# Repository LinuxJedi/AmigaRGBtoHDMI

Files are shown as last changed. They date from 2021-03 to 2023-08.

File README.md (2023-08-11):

# AmigaRGBtoHDMI

LinuxJedi's designs for Amiga RGBtoHDMI boards.

**ATTENTION PI Zero 2W users**: You can now use a Pi Zero 2W with the CPLD RGBtoHDMI using the December 24th 2021 release.

## Amiga RGBtoHDMI Tester

If you are a builder of these boards I have designed a tester that safely tests these boards without requiring a Denise or Amiga. This reduces any potential damage and test if you don't have a specific Amiga model. These can be found [on Tindie](https://www.tindie.com/products/linuxjedi/amiga-rgbtohdmi-tester/).

## Choosing a CPLD

I am deliberately vague in which CPLD can be used in the boards here because many variants will work. Given chip shortages in recent years, you might want to pick any chip you can obtain rather than what is normally cheapest. I'll give a breakdown of what the model numbers look like and what to look out for. As an example I'll use `XC9572XL-10VQG44C`:

* `XC9572XL` - This part of the model number is required. Defines the type of logic chip and the number of logic cells. This is what you should search for from your supplier and then use the below to pick the right chip for you.
* `10` - is the maximum speed grade in ns. 10 is the slowest (cheapest) you can buy. The max speed this board will go is 35ns, so 10ns is plenty.
* `VQ` - means it is a QFP. You could modify the board to accept the PLCC variant, but that would require you to make some changes in KiCad. The firmware is compatible with both.
* `G` - means lead-free / RoHS compliant. Without the `G` means the legs have lead.
* `44` - number of pins. You could in-theory modify the board for more pins in KiCad. This would require a firmware change too, which in-turn means modifying the firmware loader, so I don't recommend it.
* `C` - Consumer grade (cheapest), if there is an `I` here that means "Industrial grade" (more expensive) and `A` means "Automotive grade" (crazy expensive). This mostly defines the max/min temperature the chip will work at.

My recommendation if you can obtain it, is the XC9572XL-10VQG44C (or without the `G`). But the only important parts are the `XC9572XL`, the `VQ` and the `44`.

## Projects in This Tree

### Amiga500CPLD

Amiga 500 CPLD variant that does not require a jumper and has no sparkling pixel issues.

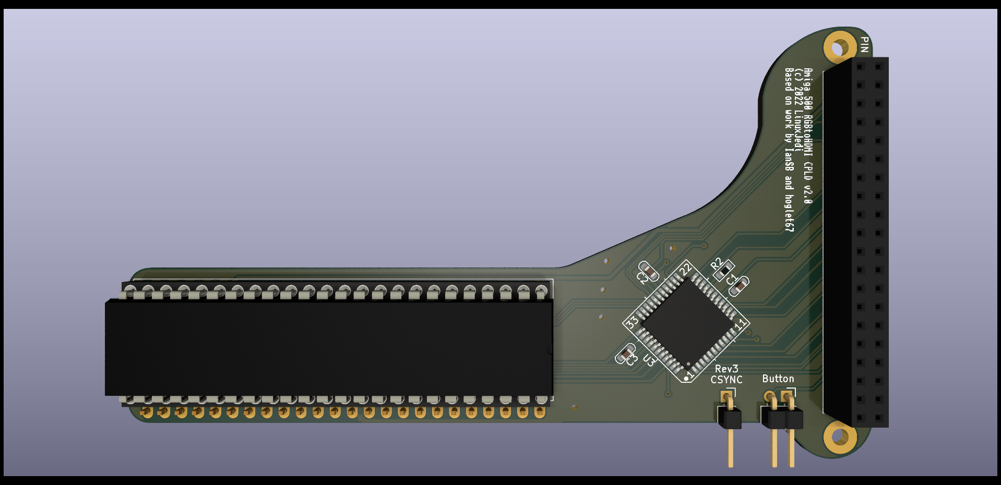
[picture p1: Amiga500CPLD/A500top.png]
Amiga 500 CPLD RGBtoHDMI


### Amiga2000CPLDSlot

Amiga 2000 CPLD variant that does not require a jumper and has no sparkling pixel issues

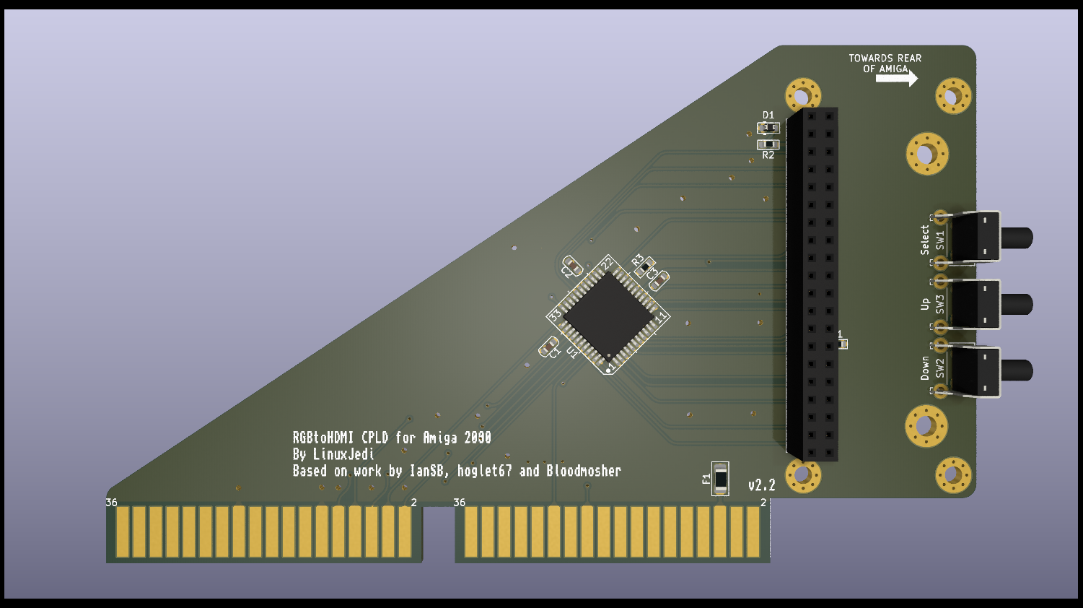
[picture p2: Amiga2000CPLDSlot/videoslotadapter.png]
Amiga 2000 CPLD Slot


### Amiga1000CPLD

Amiga 1000 CPLD variant that does not require a jumper and has no sparkling pixel issues

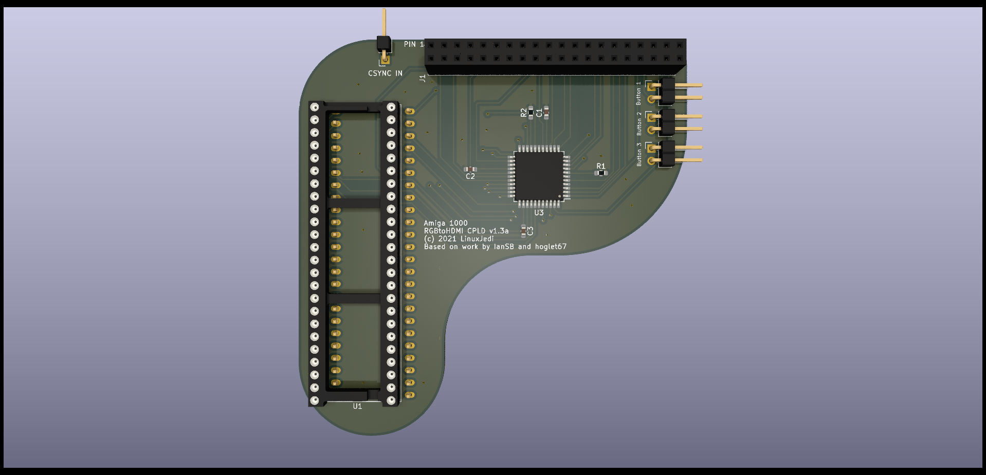
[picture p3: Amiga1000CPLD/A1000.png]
Amiga 1000 CPLD


### Legacy boards

The legacy boards directory contains:

* Amiga 2000 RGBtoHDMI v2
* Amiga 2000 CPLD RGBtoHDMI v1.2
* Amiga 2000 CPLD RGBtoHDMI v2.1

These have been superseeded by the Amiga 2000 CPLD RGBtoHDMI v2.2 board.

* Amiga 500 CPLD v1

This has been superseeded by the Amiga 500 CPLD RGBtoHDMI v2.0 board.

## Other versions

- c0pperdragon's - The excellent original c0pperdragon design can be found at: https://github.com/c0pperdragon/Amiga-Digital-Video/
- solarmon's - Improved versions of c0pperdragon's design to relocate the Pi and add additional features:https://github.com/solarmon/RGBtoHDMI

Please add pull requests to link to your variants here.

## Software

The software used for this project can be found at https://github.com/hoglet67/RGBtoHDMI/

## Troubleshooting

### Cannot use the CPLD flash menu

By default the RGBtoHDMI software is in three button mode. You need to copy the profiles in the instructions for your board which sets up a few things including the single button mode.

## Ready Built Boards

If you want a ready built board for either design please contact andrew@linuxjedi.co.uk and I can put you in touch with whoever is building / selling at a reasonable price.

Likewise if you are a someone selling these designs, please let me know if you want me to put you in touch with buyers who contact me.

I also sell some of these designs [on Tindie](https://www.tindie.com/stores/linuxjedi/).

Alternatively I've made the PCBs available on PCBWay here: https://www.pcbway.com/project/member/?bmbno=0369642B-E3DA-48

## Sponsorship

If you like these projects and have built / sold a few yourself, please consider sponsoring. R&D for these projects isn't cheap and the sponsorship money goes into more designs for the future. Links for this are can be found in the "Sponsor" button at the top of the GitHub page for this project.

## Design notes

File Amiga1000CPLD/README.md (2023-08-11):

# Amiga 1000 CPLD Adapter V1

Amiga 1000 CPLD

This adaptor uses a CPLD to pass the RGB and sync signals from the Amiga 1000 Denise socket to the Rasperry Pi Zero. It derives the pixel clock in a very different way to other designs and therefore does not require a jumper for Denise / Super Denise and has no "sparkling" pixel issues. It also has the advantage of being firmware upgradable if there are any issues found in the logic.

**NOTE:** There is an error in v1.1 boards, the text starting "IF YOU CAN READ THIS" is on the wrong side and shoud not be covered up by the Pi. The Pi goes outwards from the board.

**ATTENTION PI Zero 2W users**: You can now use a Pi Zero 2W with the CPLD RGBtoHDMI using the December 24th 2021 release.

## BOM

| Symbol | Component |
| --- | --- |
| C1, C2, C3 | 0.1uF 0603 |
| J1 | 2x20pin socket 2.54mm |
| J2 | 1pin right angle header 2.54mm |
| JButton1 - 3 | 2pin right angle header 2.54mm |
| R1 | 1K 0603 |
| R2 | 4.7K 0603 |
| U1 | 48pin DIP socket 2.54mm |
| U2 | 2x24pin SILs machined pins 2.54mm |
| U3 | XC9572XL 44pin QFP |

### Notes

- It is important that R1 is 1K due to the low value of the internal pull resistor in GPIO0 of the Pi, the other pull resistors are more flexible. If the value is too high then the software won't detect this is an Amiga board and won't show the correct firmware in the recovery menu.
- This board can be used in single button mode with just JButton1 or with three button mode.
- J2 is optional if you have already wired CSYNC to the Denise socket

## CSYNC

**NOTE**: If you have a Rejouvenator in your Amiga 1000, this patches the CSYNC and you don't need a patch wire, using the CSYNC pin can cause sync issues with a Rejouvenator.

The Amiga 1000 does not have CSYNC wired to Denise. There are two ways around this, the first is to wire CSYNC to the Denise socket on the motherboard using a patch wire. This is pin 8 of UA6 to pin 32 of Denise as below:

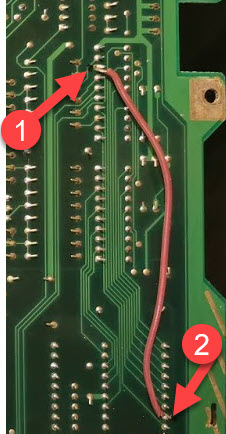
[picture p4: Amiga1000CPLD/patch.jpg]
PAL CSYNC patch


Alternatively you can use the "CSYNC IN" on the RGB to HDMI board to hook onto the relevant CSYNC signal. This is pin 8 or UA6 as can be seen below (for both PAL and NTSC):

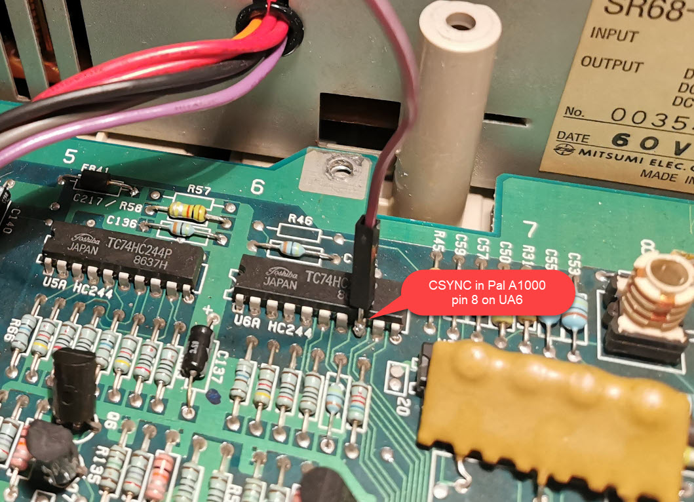
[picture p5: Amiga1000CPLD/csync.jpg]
PAL CSYNC pin


Thanks to @SirCathal for the above two photos.

## Pi Software Installation

The software on the Pi should be at least the latest 20210529 release from the [main tree](https://github.com/hoglet67/RGBtoHDMI/releases) or the latest [IanSB beta release](https://github.com/IanSB/RGBtoHDMI/releases) extracted onto a micro SD card in FAT32 format.

You need to copy some canned profile files into place for the board:

* `Amiga_CPLD_Readme/Amiga_CPLD_Setup/profile_6-12_BIT_RGB.txt` to the root of the SD card
* `Amiga_CPLD_Readme/Amiga_CPLD_Setup/Profiles/Default.txt` to the `Profiles` directory

This resolves some issues with mode switching, particularly on NTSC machines. The profile copied will automatically set `single_button_mode`.

## Flashing the CPLD

The CPLD will need flashing with the `6-12_BIT_RGB_CPLD` firmware. The other firmware options are not compatible with the profiles.

If you have followed the software steps above you will get a recovery menu, select `6-12_BIT_RGB_CPLD`, confirm and the Pi will flash the CPLD and reboot.

## Initial Setup

You may see a shimmer or wavy effect. This is because the phase is set incorrectly and needs calibration, this is a one-off easy thing to do. If you have a static image such as the Kickstart 1.3 boot screen or Workbench with no mouse movement you can use the "Auto Calibrate Video Settings" option (it will require you to select twice to activate). Alternatively you can go into the "Sampling" menu and change the "Sampling Phase" until the image looks correct. Typically 0, 3 or 5 will work fine, but it could be different in each machine.

Once calibrated choose "Save Configuration" and this will be remembered for subsequent boots.

## Buying PCBs

I've made the [PCBs available on PCBWay here](https://www.pcbway.com/project/shareproject/Amiga_1000_CPLD_RGBtoHDMI_v1_1.html).

Assembled boards are also available from me [on Tindie](https://www.tindie.com/products/linuxjedi/amiga-1000-cpld-rgbtohdmi/).

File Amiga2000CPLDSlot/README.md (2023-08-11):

# Amiga CPLD Video Slot Adapter

Amiga CPLD 2000 Slot

This adaptor uses a CPLD to pass the RGB and sync signals from the Amiga 2000 video slot to the Rasperry Pi Zero. It derives the pixel clock in a very different way to other designs and therefore does not require a jumper for Denise / Super Denise and has no "sparkling" pixel issues. It also has the advantage of being firmware upgradable if there are any issues found in the logic.

Version 2 of this board is logically identical to version 1, but is designed to be easier to build and easier for the user to install. The Pi faces the rear of the Amiga so that the HDMI can be plugged directly into it and instead of wires it uses physical buttons.

Version 2.2 has been changed to make the board smaller. It includes a fuse due to a few users misaligning the Pi, causing a sort between +5v and GND which in-turn caused the +5v line to burn. It also includes an optional LED to indicate there is power to the +5v line (that the fuse hasn't blown).

**ATTENTION PI Zero 2W users**: You can now use a Pi Zero 2W with the CPLD RGBtoHDMI using 24th December 2021 release onwards.

## BOM

| Symbol | Component |
| --- | --- |
| C1 - C3 | 0.1uF 0603 |
| J1 | 2x20pin socket 2.54mm |
| SW1 - SW3 | SKHHLQA010 90° SPST 8.35mm push button |
| R1 | 1K 0603 |
| R3 | 4.7K 0603 |
| U1 | XC9572XL 44pin QFP |
| F1 | Littlefuse 1206L075THYR |
| D1 | Any 0603 LED |
| R2 | A 0603 resistor between the LED and +5v line |

### Notes

- R1 needs to be a 1K pull resistor due to the low value internal I2C pull resisors in the Pi. If the value is too high then the software won't detect this is an Amiga board and won't show the correct firmware in the recovery menu.
- The F1 fuse can be any 1206 fuse with a hold current of 0.75A or greater. You could also just use a 0ohm resistor if you do not wish to use a fuse.
- D1 and R2 are optional, used as indication that the 5V line is being provided to the Pi and there is no fuse trip.
- This board can be used in single button mode with just SW1.
- You can use smaller push buttons but they won't reach outside of the A2000's case, this may be fine with the correct bracket.
- Brackets for the original A2000 RGBtoHDMI boards are **NOT** compatible, the mounting holes have been moved.
- It is recommended you use 4x11mm M2.5 standoffs to hold the Pi in place, alternatively you can use 10mm M2.5 standoffs and 1mm M2.5 washers.
- The board was designed in a KiCad 6.99 nightly build, you will need to use 6.99 (or higher if you are reading this after 7.0 is released) to be able to use the files.

## Pi Software Installation

The software on the Pi should be at least the latest 20211224 release from the [main tree](https://github.com/hoglet67/RGBtoHDMI/releases) or the latest [IanSB beta release](https://github.com/IanSB/RGBtoHDMI/releases) extracted onto a micro SD card in FAT32 format.

You need to copy some canned profile files into place for the board:

* `Amiga_CPLD_Readme/Amiga_2000_CPLD_Setup/profile_6-12_BIT_RGB.txt` to the root of the SD card
* `Amiga_CPLD_Readme/Amiga_2000_CPLD_Setup/Profiles/Default.txt` to the `Profiles` directory

This resolves some issues with mode switching, particularly on NTSC machines.

If you wish to use three button mode, you then need to edit `Profiles/Default.txt` and set the option `single_button_mode=0` (it is near the bottom of the file).

## Flashing the CPLD

The CPLD will need flashing with the `6-12_BIT_RGB_CPLD` firmware. The other firmware options are not compatible with this board.

If you have followed the software steps above you will get a recovery menu, select `6-12_BIT_RGB_CPLD`, confirm and the Pi will flash the CPLD and reboot.

## Initial Setup

You may see a shimmer or wavy effect. This is because the phase is set incorrectly and needs calibration, this is a one-off easy thing to do. If you have a static image such as the Kickstart 1.3 boot screen or Workbench with no mouse movement you can use the "Auto Calibrate Video Settings" option (it will require you to select twice to activate). Alternatively you can go into the "Sampling" menu and change the "Sampling Phase" until the image looks correct. Typically 0, 3 or 5 will work fine, but it could be different in each machine.

Once calibrated choose "Save Configuration" and this will be remembered for subsequent boots.

## Buying PCBs

You can buy PCBs from my store, [Retro Supplies](https://www.retrosupplies.co.uk/amiga-rgbtohdmi/rgbtohdmi-for-amiga-2000-v22-pcb-only).

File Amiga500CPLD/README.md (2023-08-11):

# Amiga 500 CPLD RGBtoHDMI

Amiga 500 CPLD RGBtoHDMI

This adaptor uses a CPLD to pass the RGB and sync signals from the Amiga 500 Denise socket to the Rasperry Pi Zero. It derives the pixel clock in a very different way to the c0pperdragon design and therefore does not require a jumper for Denise / Super Denise and has no "sparkling" pixel issues. It also has the advantage of being firmware upgradable if there are any issues found in the logic.

**ATTENTION PI Zero 2W users**: You can now use a Pi Zero 2W with the CPLD RGBtoHDMI using the December 24th 2021 release.

## BOM

| Symbol | Component |
| --- | --- |
| C1 - C3 | 0.1uF 0603 |
| J1 | 2x20pin socket 2.54mm |
| JP1 | 2pin right angle header 2.54mm |
| J2 | 1pin right angle header 2.54mm |
| R1 | 1K 0603 |
| R2 | 4.7K 0603 |
| U1 | 48pin DIP socket 2.54mm |
| U2 | 2x24pin SILs machined pins 2.54mm |
| U3 | XC9572XL 44pin QFP |

### Notes

- It is important that R1 is 1K due to the low value of the internal pull resistor in GPIO0 of the Pi, the other pull resistors are more flexible (R1 is optional as the Pi will pull this internally). If the value is too high then the software won't detect this is an Amiga board and won't show the correct firmware in the recovery menu.
- You'll need some kind of push button to connect to JP1
- J2 is optional, it is only needed for revision 3 motherboards to clip onto pin 9 of U41 on the Amiga (photo coming soon)
- The Pi mounting holes are M2.5, 11mm posts or 10mm with 1mm washers are recommended

## Pi Software Installation

The software on the Pi should be at least the latest 20210529 release from the [main tree](https://github.com/hoglet67/RGBtoHDMI/releases) or the latest [IanSB beta release](https://github.com/IanSB/RGBtoHDMI/releases) extracted onto a micro SD card in FAT32 format.

You need to copy some canned profile files into place for the board:

* `Amiga_CPLD_Readme/Amiga_CPLD_Setup/profile_6-12_BIT_RGB.txt` to the root of the SD card
* `Amiga_CPLD_Readme/Amiga_CPLD_Setup/Profiles/Default.txt` to the `Profiles` directory

This resolves some issues with mode switching, particularly on NTSC machines. The profile copied will automatically set `single_button_mode`.

## Flashing the CPLD

The CPLD will need flashing with the `6-12_BIT_RGB_CPLD` firmware. The other firmware options are not compatible with the profiles.

If you have followed the software steps above you will get a recovery menu, select `6-12_BIT_RGB_CPLD`, confirm and the Pi will flash the CPLD and reboot. You can then jump to the Initial Setup section below.

## Initial Setup

You may also a shimmer or wavy effect. This is because the phase is set incorrectly and needs calibration, this is a one-off easy thing to do. If you have a static image such as the Kickstart 1.3 boot screen or Workbench with no mouse movement you can use the "Auto Calibrate Video Settings" option (it will require you to select twice to activate). Alternatively you can go into the "Sampling" menu and change the "Sampling Phase" until the image looks correct. Typically 0, 3 or 5 will work fine, but it could be different in each machine.

Once calibrated choose "Save Configuration" and this will be remembered for subsequent boots.

## Buying PCBs

I've made the [PCBs available on PCBWay](https://www.pcbway.com/project/shareproject/Amiga_500_CPLD_RGBtoHDMI_v2_fb52eff9.html).

You can also purchase PCBs from me [via Tindie](https://www.tindie.com/products/linuxjedi/amiga-500-rgb-to-hdmi-pcb/).

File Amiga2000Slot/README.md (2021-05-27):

# Amiga Video Slot Adapter V2

**NOTE:** This is now a legacy project, please see the Amiga 2000 CPLD version also in this GitHub repository.

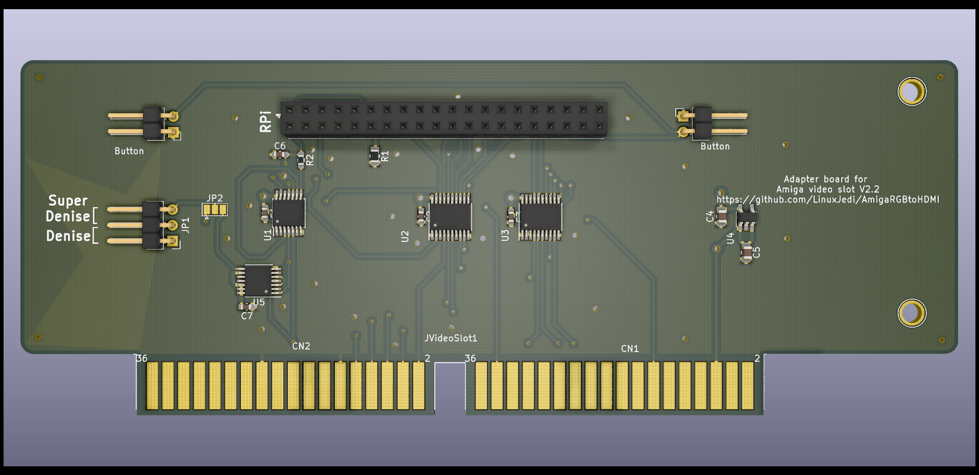
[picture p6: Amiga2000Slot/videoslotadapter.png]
Amiga 2000 Slot


This adapter builds on the ideas from the Amiga Denise adapter V2, adapted for use in big box Amiga video slots. LinuxJedi's Version 2 is based on Bloodmosher's V1 design but has been modified for reliability and to provide timing options.

The main differences from the Amiga Denise V2 are:
- The 7MHZ signal is derived via C1 XNOR C3 since 7MHZ is not available directly from the video slot
- Two button connectors allow for both a rear slot cover bracket button and another to be used, mounted wherever desired

The main differences from the V1 slot adaptor are:
- ICs moved to more appropriate locations
- Fixed floating inputs on U5
- Added ground pour and more grounding points for RGB and Pi
- Manually rerouted everything (fewer signal vias)
- Added option to use U1 for the inverted C1, C3 XNOR (which makes it an XOR)
- Added RC based delay option
- Input capacitor added to the regulator
- Rounded the corners a little more

## LinuxJedi's build notes

### Options

 - For U1 to handle Super Denise timing add 0ohm between pin 1 and 2 of JP2
 - For U5 to handle Super Denies timing add 0ohm between pin 2 and 3 of JP2
 - C6 is an optional capacitor for timing delay, 47pF has been recommended by some but can be left unpopulated
 - R2 is a resistor for timing delay, it needs to be populated, only 0ohm has been tested

### Recommended build

This is what has worked for me, YMMV.

 - Leave U5 and C7 unpopulated
 - 0ohm 0603 (or wire/solder short) between pins 1 and 2 of JP2
 - 0ohm 0603 in R2
 - C6 unpopulated or 47pF 0603
 - Use TI 74LVC ICs (Toshiba 74VHC for U1 has also been tested with this design and appear to work)
 - Use a regulator that is rated for 300mA or higher (I use NCP161 regulators in my builds)

### Recommended ordering

If you are ordering from JLCPCB I recommend the following:

 - Surface Finish: ENIG
 - Gold Fingers: Yes
 - 45° finger chamfered: yes

## Installation notes

- Set the Denise jumper according to which Denise is in your Amiga (Super Denise for 8373, Denise for 8362)
- Orient the PCB such that the end with bracket mounting holes faces the rear of the machine

## Sparkles in the image

There are a few things to try. First if the sparkling is extreme, try swapping the Denise/Super Denise jumper to the opposite setting, this changes the clock used for the RGB timing. Then you can try a 47pF capacitor in C6 and using 74VHC ICs instead of 74LVC.

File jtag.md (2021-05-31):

# JTAG pins

The JTAG is accessible on the Pi GPIO header, so you can plug pins into the header to use a JTAG programmer to flash it. If you don't have a JTAG programmer I have [documented how to build one out of a Raspberry Pi](https://linuxjedi.co.uk/2020/12/01/programming-xilinx-jtag-from-a-raspberry-pi/). Note that the GPIO pins xc3sprog use for JTAG are different to the RGBtoHDMI GPIO JTAG pins.

The JTAG pins are:

| GPIO number | GPIO pin | Signal |
| --- | --- | --- |
| N/A | 1 or 17 | 3v3 |
| N/A | 6, 9, 14, 20, 25, 30, 34 or 39 | GND |
| 0 | 27 | TDI |
| 1 | 28 | TMS |
| 20 | 38 | TCK |
| 24 | 18 | TDO |

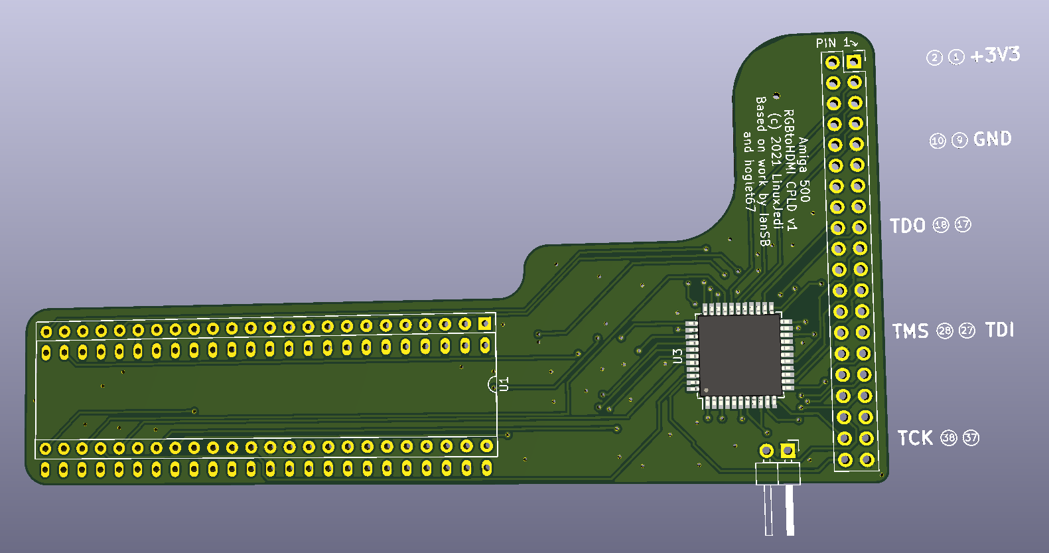
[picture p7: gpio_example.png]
GPIO Example


If you are using Pi xc3sprog method from the link above you will need to compile the JED file which can be done in the free Xilinx ISE Design Suite.

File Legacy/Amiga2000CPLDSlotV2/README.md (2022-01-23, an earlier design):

# Amiga CPLD Video Slot Adapter

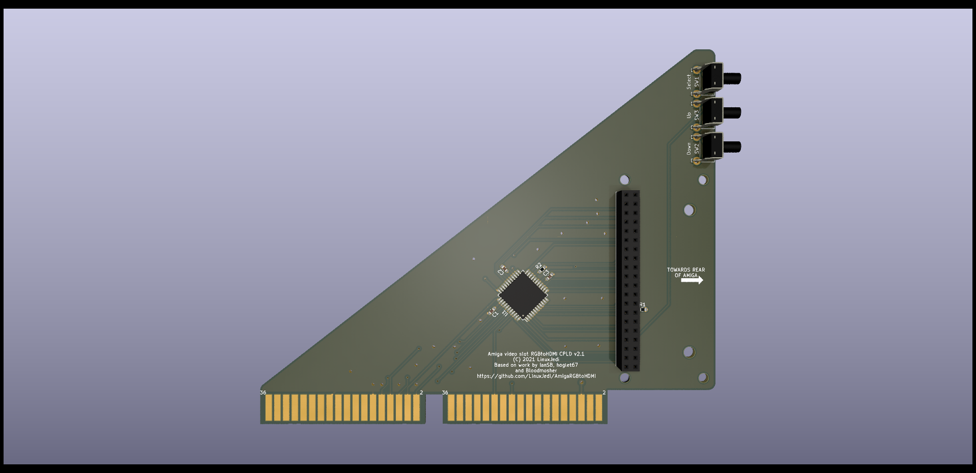
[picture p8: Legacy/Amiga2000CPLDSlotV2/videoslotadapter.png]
Amiga CPLD 2000 Slot


This adaptor uses a CPLD to pass the RGB and sync signals from the Amiga 2000 video slot to the Rasperry Pi Zero. It derives the pixel clock in a very different way to other designs and therefore does not require a jumper for Denise / Super Denise and has no "sparkling" pixel issues. It also has the advantage of being firmware upgradable if there are any issues found in the logic.

Version 2 of this board is logically identical to version 1, but is designed to be easier to build and easier for the user to install. The Pi faces the rear of the Amiga so that the HDMI can be plugged directly into it and instead of wires it uses physical buttons.

**ATTENTION PI Zero 2W users**: You can now use a Pi Zero 2W with the CPLD RGBtoHDMI using 24th December 2021 release onwards.

## BOM

| Symbol | Component |
| --- | --- |
| C1 - C3 | 0.1uF 0603 |
| J1 | 2x20pin socket 2.54mm |
| SW1 - SW3 | SKHHLQA010 90° SPST 8.35mm push button  |
| R1 | 1K 0603 |
| R2 | 4.7K 0603 |
| U1 | XC9572XL-10VQG44C |

### Notes

- R1 needs to be a 1K pull resistor due to the low value internal I2C pull resisors in the Pi. If the value is too high then the software won't detect this is an Amiga board and won't show the correct firmware in the recovery menu.
- This board can be used in single button mode with just SW1.
- You can use smaller push buttons but they won't reach outside of the A2000's case, this may be fine with the correct bracket.
- Brackets for the original A2000 RGBtoHDMI boards are **NOT** compatible, the mounting holes have been moved.
- It is recommended you use 4x11mm M2.5 standoffs to hold the Pi in place, alternatively you can use 10mm M2.5 standoffs and 1mm M2.5 washers.

## Pi Software Installation

The software on the Pi should be at least the latest 20211224 release from the [main tree](https://github.com/hoglet67/RGBtoHDMI/releases) or the latest [IanSB beta release](https://github.com/IanSB/RGBtoHDMI/releases) extracted onto a micro SD card in FAT32 format.

You need to copy some canned profile files into place for the board:

* `Amiga_CPLD_Readme/Amiga_2000_CPLD_Setup/profile_6-12_BIT_RGB.txt` to the root of the SD card
* `Amiga_CPLD_Readme/Amiga_2000_CPLD_Setup/Profiles/Default.txt` to the `Profiles` directory

This resolves some issues with mode switching, particularly on NTSC machines.

If you wish to use three button mode, you then need to edit `Profiles/Default.txt` and set the option `single_button_mode=0` (it is near the bottom of the file).

## Flashing the CPLD

The CPLD will need flashing with the `6-12_BIT_RGB_CPLD` firmware. The other firmware options are not compatible with this board.

If you have followed the software steps above you will get a recovery menu, select `6-12_BIT_RGB_CPLD`, confirm and the Pi will flash the CPLD and reboot.

## Initial Setup

You may see a shimmer or wavy effect. This is because the phase is set incorrectly and needs calibration, this is a one-off easy thing to do. If you have a static image such as the Kickstart 1.3 boot screen or Workbench with no mouse movement you can use the "Auto Calibrate Video Settings" option (it will require you to select twice to activate). Alternatively you can go into the "Sampling" menu and change the "Sampling Phase" until the image looks correct. Typically 0, 3 or 5 will work fine, but it could be different in each machine.

Once calibrated choose "Save Configuration" and this will be remembered for subsequent boots.

## Buying PCBs

I've made the [PCBs available on PCBWay](https://www.pcbway.com/project/shareproject/Amiga_2000_CPLD_RGBtoHDMI_v2_1_83f23b25.html).

A limited edition version of this board with the LinuxJedi logo containing a glowing lightsaber can be found [on Tindie](https://www.tindie.com/products/linuxjedi/amiga-2000-rgb-to-hdmi/).

## Bracket

Comming soon.

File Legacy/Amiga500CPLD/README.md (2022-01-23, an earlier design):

# Amiga 500 CPLD RGBtoHDMI

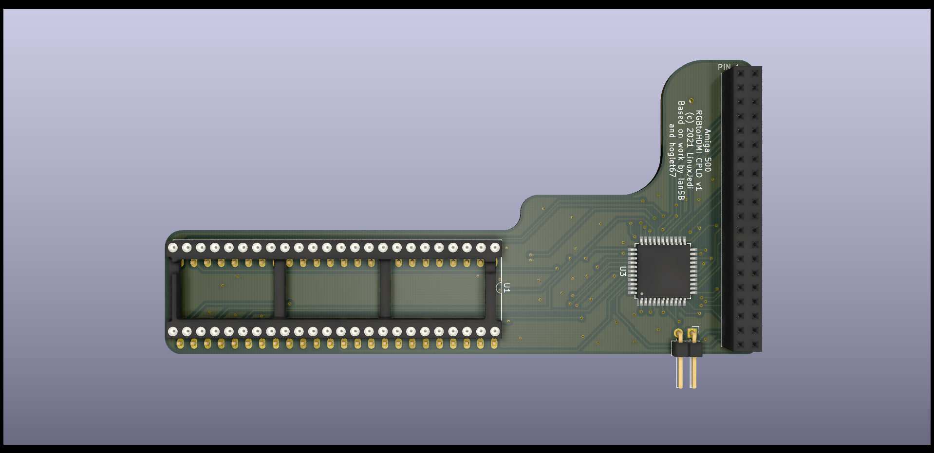
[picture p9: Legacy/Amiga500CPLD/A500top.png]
Amiga 500 CPLD RGBtoHDMI


This adaptor uses a CPLD to pass the RGB and sync signals from the Amiga 500 Denise socket to the Rasperry Pi Zero. It derives the pixel clock in a very different way to the c0pperdragon design and therefore does not require a jumper for Denise / Super Denise and has no "sparkling" pixel issues. It also has the advantage of being firmware upgradable if there are any issues found in the logic.

**ATTENTION PI Zero 2W users**: You can now use a Pi Zero 2W with the CPLD RGBtoHDMI using the December 24th 2021 release.

## BOM

| Symbol | Component |
| --- | --- |
| C1 | Optional 10uF 1206 |
| C2, C3, C4 | 0.1uF 0603 |
| J1 | 2x20pin socket 2.54mm |
| JP1 | 2pin right angle header 2.54mm |
| R1, R2 | 1K 0603 |
| R3 | 4.7K 0603 |
| U1 | 48pin DIP socket 2.54mm |
| U2 | 2x24pin SILs machined pins 2.54mm |
| U3 | XC9572XL-10VQG44C |

### Notes

- It is important that R2 is 1K due to the low value of the internal pull resistor in GPIO0 of the Pi, the other pull resistors are more flexible (R1 is optional as the Pi will pull this internally). If the value is too high then the software won't detect this is an Amiga board and won't show the correct firmware in the recovery menu.
- In my own builds I do not populate C1. You could use this for a 3.9v LED I guess
- You'll need some kind of push button to connect to JP1

## Pi Software Installation

The software on the Pi should be at least the latest 20210529 release from the [main tree](https://github.com/hoglet67/RGBtoHDMI/releases) or the latest [IanSB beta release](https://github.com/IanSB/RGBtoHDMI/releases) extracted onto a micro SD card in FAT32 format.

You need to copy some canned profile files into place for the board:

* `Amiga_CPLD_Readme/Amiga_CPLD_Setup/profile_6-12_BIT_RGB.txt` to the root of the SD card
* `Amiga_CPLD_Readme/Amiga_CPLD_Setup/Profiles/Default.txt` to the `Profiles` directory

This resolves some issues with mode switching, particularly on NTSC machines. The profile copied will automatically set `single_button_mode`.

## Flashing the CPLD

The CPLD will need flashing with the `6-12_BIT_RGB_CPLD` firmware. The other firmware options are not compatible with the profiles.

If you have followed the software steps above you will get a recovery menu, select `6-12_BIT_RGB_CPLD`, confirm and the Pi will flash the CPLD and reboot. You can then jump to the Initial Setup section below.

## Initial Setup

You may also a shimmer or wavy effect. This is because the phase is set incorrectly and needs calibration, this is a one-off easy thing to do. If you have a static image such as the Kickstart 1.3 boot screen or Workbench with no mouse movement you can use the "Auto Calibrate Video Settings" option (it will require you to select twice to activate). Alternatively you can go into the "Sampling" menu and change the "Sampling Phase" until the image looks correct. Typically 0, 3 or 5 will work fine, but it could be different in each machine.

Once calibrated choose "Save Configuration" and this will be remembered for subsequent boots.

## Buying PCBs

I've made the [PCBs available on PCBWay](https://www.pcbway.com/project/shareproject/Amiga_500_CPLD_RGBtoHDMI_v1.html)

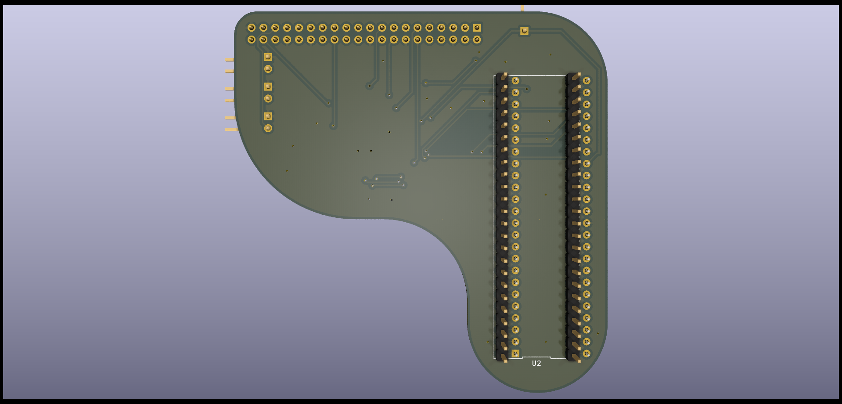
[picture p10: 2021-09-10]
Amiga1000CPLD/A1000 bottom.png

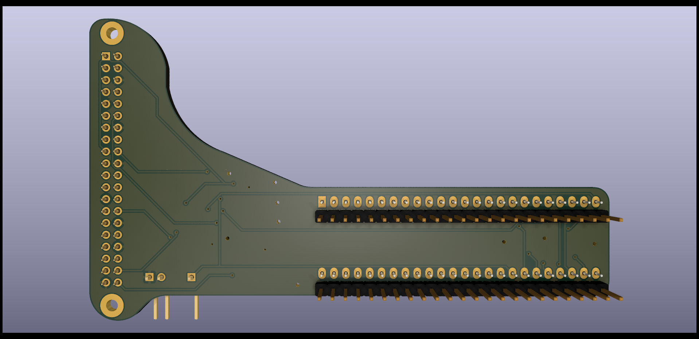
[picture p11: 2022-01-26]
Amiga500CPLD/A500bottom.png

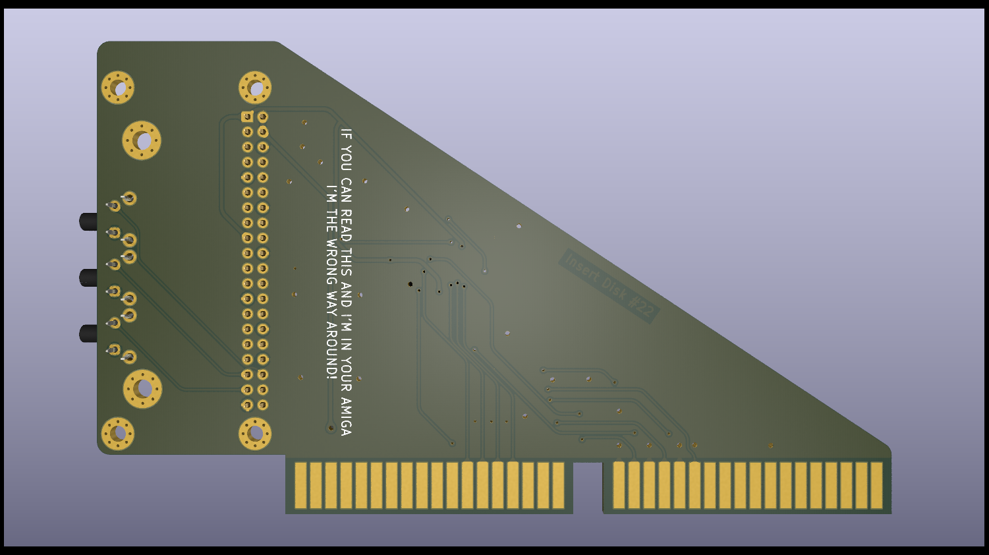
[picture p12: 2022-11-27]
Amiga2000CPLDSlot/videoslotadapter_bottom.png

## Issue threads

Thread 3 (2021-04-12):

Add option for two more buttons to the A2000 CPLD version

LinuxJedi, 2021-04-12:
This was requested by someone, can't think of a reason not to.

LinuxJedi, 2021-04-12:
Fixed in v1.1

Closed 2021-04-12.

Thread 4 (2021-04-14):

Add FF OSD header

LinuxJedi, 2021-04-14:
Requested via Discord to add it to the CPLD designs

LinuxJedi, 2021-04-17:
This is currently blocked as the GPIO pin for FF OSD is currently used for JTAG in the CPLD design.

LinuxJedi, 2021-05-10:
Blocked issue is fixed, but the OSD will have sync issues with the current design of the interface. Leaving this open for now but not a high priority until a better way is found.

LinuxJedi, 2021-12-08:
Closing this for now as others have incorporated it into their designs.

Closed 2021-12-08.

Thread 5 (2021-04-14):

Please adjust the new CPLD Adapter for the A1000

SirCathal, 2021-04-14:
Hello, I'm really looking forward to the CPLD version for the A500. I've already ordered components.
But would it be possible that you adapt the A500 version so that it fits into the A1000.
In the A1000, the Denise chip is rotated 180 ° compared to the A500. That means with the new adapter the Pi would hang out of the front of the case. So it doesn't fit in.

It would look like this:
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

Based on your new adapter, the Pi would simply have to be on the other side, not to the right but to the left (see photo for explanation).
So it could work so that neither the front nor the power supply are in the way.
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

Since the A1000 always has flickering pixels, because the timing is just a little different there than in the newer Amigas, your solution would be perfect for the A1000.

@LinuxJedi
It would be totally great if you could adjust that accordingly. Unfortunately, I can't design circuit boards, but if you can do that I would test it right away.

LinuxJedi, 2021-04-14:
Sure, I won't be able to until this weekend at the earliest, but should only take an hour or so.

SirCathal, 2021-04-14:
That would be great! Time is not a problem. Here in Germany I have to wait a week or two for the chips that I ordered in the US to arrive anyway.
Here they were unfortunately not in stock or significantly more expensive.
Thank you very much in advance!

LinuxJedi, 2021-04-17:
@SirCathal I've just merged #6 which might do the trick. Let me know what you think.

rlake, 2021-05-03:
Waiting on boards to arrive but can give this a go on an NTSC board assuming a faster (5 or 7) CPLD is fine.

LinuxJedi, 2021-05-03:
> Waiting on boards to arrive but can give this a go on an NTSC board assuming a faster (5 or 7) CPLD is fine.

Yes, a faster CPLD will work but is more expensive, Mouser still have stock if that helps: https://www.mouser.co.uk/ProductDetail/Xilinx/XC9572XL-10VQ44C

I should note that you will need to modify your A1000 board to add CSYNC to the Denise socket. I'll soon do an updated revision soon to optionally hook a wire elsewhere to provide that. @SirCathal has details of the change that is required.

rlake, 2021-05-03:
Sounds good, I somehow missed the non-RoHS version but no matter.

I'll try a clip onto pin 2 of U7A/MC1377 for CSYNC.

SirCathal, 2021-05-04:
In My PAL A1000, I soldered a cable from pin 8 on UA6 to pin 32 of the Denise socket under the Moterboard to get CSYNC.
Here is the fix from below the mainboard.
(1) is Pin 8 of UA6
(2) is Pin 32 of the Denise socket.
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

@LinuxJedi all parts for your A1000 adapter arrived. A friend soldered it for me because I'm not so good in soldering SMD stuff.
He already tested it with his A500 board (he don't have a A1000). There it worked very good. Now he sanded it to me and it will arrive this week. Then I will do the final Test in my A1000.
If it's done I will post Pictures and a Video.

LinuxJedi, 2021-05-04:
Perfect, thank you. When I have confirmation it is good I'll update the files to add a place to hook a wire into my board instead and write up some documentation. Can you please take a photo of the top of UA6 for me? It will help me mark in the documentation what to do.

SirCathal, 2021-05-04:
No Problem, here is the Foto. Please make sure that this is for the PAL Board with no PiggyBoard.
As far as I Know, the NTSC Board has the signal somewhere else.
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

SirCathal, 2021-05-04:
I Hope I can do test final test at the weekend. That the parcel did not move today, I think DHL hates me....

SirCathal, 2021-05-08:
@LinuxJedi
I can confirm, The A1000 Adapter works and fits perfectly in my Pal A1000 with CSYNC added as in my description above.
Thank you for this wonderful peace of hardware.

LinuxJedi, 2021-05-08:
> @LinuxJedi
> I can confirm, The A1000 Adapter works and fits perfectly in my Pal A1000 with CSYNC added as in my description above.
> Thank you for this wonderful peace of hardware.

Excellent! Glad to hear it! Can I be cheeky and ask for a photo of the motherboard with it in please? I want to see how close my estimates based on photos were :)

SirCathal, 2021-05-08:
No Problem, here the Pictures.
Ignore the black wire, it's only a ground wire to the Pi0 from old experiments.

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

rlake, 2021-05-08:
Just trying this out now. I used a JTAG cable to program the chip through GPIO, extracted RGBtoHDMI_20210322_f771e51 and changed single_button_mode=1 in Default.txt

Booting gives the CPLD Recovery Menu, which sounds wrong unless I missed some instructions. Any suggestion for where to check next? I also need to learn how to use the menu system

rlake, 2021-05-09:
Found my serial cable and well, it doesn't look good for my build for some reason! I'll have to investigate more into how the detection works before I try reflowing and/or programming again:

```
Unknown CPLD: identifier = fff
EMMC: BCM2708 controller power-cycled
Keycount = 0
CPLD  Design: Unknown
CPLD Version: f.f
```

Anyway, here's the fit for an NTSC Amiga 1000. It's a little snug with that brown "DL1" component but it's not too bad with the "piggy board". For CSYNC I'm just using a test clip from pin 8 of U6A (CSY* according to my Zorro schematics) to a wire fed under the socket to Denise pin 32.

I suppose if there's something to wish for on a final rev it'd be some optional headers for 3-button mode and the uart tx+gnd just in case! 😀

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

LinuxJedi, 2021-05-09:
> Just trying this out now. I used a JTAG cable to program the chip through GPIO, extracted RGBtoHDMI_20210322_f771e51 and changed single_button_mode=1 in Default.txt
>
> Booting gives the CPLD Recovery Menu, which sounds wrong unless I missed some instructions. Any suggestion for where to check next? I also need to learn how to use the menu system

The recovery menu doesn't work in single_button_mode in that version unfortunately, there is a bug which has been fixed but not made it into the main releases yet.

I highly recommend using the latest beta from here: https://github.com/IanSB/RGBtoHDMI/releases

Then you can set single_button_mode=1 in Default.txt and use the recovery menu properly to flash the board. It also has some NTSC specific fixes in it.

rlake, 2021-05-09:
Yeah that helped a lot! This time I generated an XSVF from Xilinx tools and dropped it into the 6-12 bit and recovery folders, but the menu didn't display the file (not sure how that's determined) so I went with the BBC firmware. RPi programmed fine:

```
CPLD  Design: 6-12_BIT_RGB
CPLD Version: 9.2
```

But that leaves me with a grey screen and no means to get back into recovery menu (to my knowledge, button doesn't have any effect; serial console shows it booting). I can't explain why the Xilinx tools with my Digilent/Adept adapter/plugin "verified" the firmware at first (and didn't detect) but the RPi programmed firmware is good.

I'll try and dig through the software later to see what's going on with the menu, recovery, why it's in "Acorn" mode etc. Hardware seems good so far though, stuck with software/tools debugging. :)

LinuxJedi, 2021-05-10:
Latest commit to main adds two more optional buttons and an optional pin to hook CSYNC into and a README is added. rlake's issues are being diagnosed elsewhere. I'm going to close this for now. Please feel free to open a new issue with any issues found.

Closed 2021-05-10.

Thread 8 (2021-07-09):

New build, single button mode not working, can't flash.

dabonetn, 2021-07-09:
I just built up a board, and trying the Beta36 software, and I can't get the menus to work, it acts like it's not in single button mode, so it just returns to the main menu, and if I hold it down it turns scanlines on and off.

the default.txt has been copied from Amiga_CPLD_Readme\Amiga_CPLD_Setup\Profiles to the root of the card.
And the next to the last line is.

single_button_mode=1

Any suggestions? I've tried 4gb and 32gb cards, formatted fat32 with 4k clusters.

LinuxJedi, 2021-07-09:
Hi,

The instructions state you need to copy:
* `Amiga_CPLD_Readme/Amiga_CPLD_Setup/profile_6-12_BIT_RGB.txt` to the root of the SD card
* `Amiga_CPLD_Readme/Amiga_CPLD_Setup/Profiles/Default.txt` to the `Profiles` directory

Copying `Default.txt` to the root instead of the `Profiles` directory will not overwrite the stock `Default.txt` and therefore will not enable `single_button_mode`.

dabonetn, 2021-07-09:
That was it.. Problem lies between keyboard and chair.. Thanks..

Closed 2021-07-09.

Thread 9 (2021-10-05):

Gerber files, graphics need to be moved to silkscreen layer

goose2000, 2021-10-05:
Hi, I ran into the issue today at PCBWay :

Hi John, For PCB order No. W234910ASB2,please see the image,the cartoon image can not be made on solder mask layer because the width of line is too thin. Please consider move it to silkscreen layer,and expand line to 0.075mm at least. Waitting for your new gerber file.

They want the image moved and line bigger. I don't know how to edit the gerber files / PCB software.

https://pcbwayfile.s3-us-west-2.amazonaws.com/msgfile/21/10/04/2214162170132t.png

LinuxJedi, 2021-10-06:
Huh... they didn't have a problem with it before now. I'll remove the image and update the gerbers when I get time later today.

Closed 2021-10-06.

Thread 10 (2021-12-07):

Help: Pi Zero not powering up

maded2, 2021-12-07:
hi,
   Thank you for the putting the work in for this project.

   I have A500 Rev 3 board.  I've just made this board.  It appears that the Pi Zero wouldn't boot up when plugged into the RGBtoHDMI adaptor, but it appears to boot when not plugin.   Any pointer to debug will be very helpful.  I've checked the soldering and it appears to be good.

thanks,
eddie

maded2, 2021-12-07:
fantastic,  so will this caused the Pi zero not booting up?

LinuxJedi, 2021-12-07:
OK, found the schematic (https://museum.syssrc.com/static/Amiga_500_Introduction.pdf).

The Pi should be booting but won't do anything until it gets a CSYNC signal, the button will not function either. If you are lucky you might see a flash of colour but this usually happens faster than monitors can show. The monitor will go back into DPMS immediately.

Did you get as far as the firmware recovery screen for first time boot?

The workaround for rev 3 CSYNC is to connect U41 pin 9 to pin 32 on Denise, this will provide CSYNC on the Denise which the RGBtoHDMI board can pick up.

maded2, 2021-12-07:
ok, I will give it a try tomorrow.  I haven't make it to the recovery screen yet, as I said the Pi zero appears not to boot at all.

LinuxJedi, 2021-12-07:
OK, there may be something else at play as well then. Can you please attach a good as possible photo of the CPLD soldering and the underside surface mount soldering?

Also did the RGB standard Amiga connector work whilst the board was plugged in?

maded2, 2021-12-07:
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

the Amiga is working as expected.  I get a the B&W composite video signal and it display fine (I don't have a CRT to use the RGB video out, that's why I want to get this board to work)

LinuxJedi, 2021-12-07:
A couple of things to check, first of all there might be a solder bridge here:

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

Also, with a multimeter try to do a continuity test on one of the capacitors on the underside, this would indicate a short between 3.3v and ground which would stop the Pi booting.

maded2, 2021-12-07:
I will reflow those pins tomorrow.  continuity test  is showing a short across the capacitor.  Will reflow all the passives as well tomorrow under the scope.

many thanks.

LinuxJedi, 2021-12-07:
You might need to replace the capacitors if the reflow doesn't fix it, occasionally you can get a bad one. The short will definitely be the problem. The two pins to the right of the ones I highlighted I think are 3.3v and GND, so check if there is a short there too. Possibly check the right side of the chip, I can't tell if it is blur or if there are bridges there.

maded2, 2021-12-08:
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

fantastic, everything working now.  one of the smd passive had a short.   Then there was no sync signal.  I use your suggestion of  csync from U41 pin9 workaround, this works really well.

many thanks for your help

Closed 2021-12-08.

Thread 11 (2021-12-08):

Got one working (A1000)! But can't clear up noise.

goose2000, 2021-12-08:
Hi - Finished building and flashing and booting up v3 board tonight. It looks pretty good, but seems no matter I still get lines and a little noise even after I run the autoconfiguration. Tried a few times. My CSYNC is connected to the RGBtoHDMI pin and soldered to the U6 chip.

The TV I am using is a small and odd size resolution: 1360 x 768 - It's like a RV travel TV.

Thanks for any ideas

LinuxJedi, 2021-12-08:
Can you please take a photo of the output, a photo of the main menu on the software and a photo of the sampling menu? This should help figure out where the problem lies.

Also, are you running the auto-calibration on a static image (eg. Kickstart 1.2/1.3 screen?), it will make a bad decision if there is any motion on the image.

goose2000, 2021-12-09:
Think we can close this one L.J. - I moved on to a second board, where I did a better job on the CLPD. Hooked it up, flashed this one and it performs beautifully ! So, I had some build quality on original board.

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

LinuxJedi, 2021-12-10:
I'm glad you got it working. It could well have been a tiny solder bridge around a couple of the Xilinx pins that did it. Sometimes they are invisible to the naked eye (I've fried a Pi Zero with one thinner than a human hair).

LinuxJedi, 2021-12-10:
I believe that is the output of two different colours shorted. So that would definitely do it. A bit of flux and a light touch of the soldering iron should fix that.

goose2000, 2021-12-10:
Yep!
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
!

Closed 2021-12-09.

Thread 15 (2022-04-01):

Unable to flash (in 1 button mode)

Sedrickgates, 2022-04-01:
Hi,
I have successfully flashed 1 board and it works like a charm.... but all subsequent ones won't flash :-(
It could be due to bad CPLD of course but 1 out of 10 is a bit odd.
I have tried to clear the CPLD using the remove text file but no luck.
Interface shows Current=3-12BITBBC  xx.x (See picture). I have never flashed them, they are brand "new". Could it be that they are aready programmed with another set? (those might be pulled parts)
Is there a way to forceflash/forceclear the CPLD from the Raspberry software using the Header?
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

 Thanks
 Cédric

LinuxJedi, 2022-04-01:
The versioning is working by pulling an ID from the CPLD and matching that up with details in the Pi's software. If they were from a Chinese supplier it is more than possible they were pulled from *something* and the software is reading this as the BBC version.

Equally possible is the Pi itself could have a damaged GPIO. I would check this too. Details on how to use GPIOtest can be found here (make sure the Pi is not connected): https://forums.raspberrypi.com/viewtopic.php?t=180505

Finally, what exactly happens when you try to overwrite the flash? Does it show a flashing text or does it return immediately?

Sedrickgates, 2022-04-02:
Hi,
Thanks for your quick reply.
For GPIO, all is good and tried 2 RPi,.
I am able to erase / (re)program 1 of the CPLD and it works on the Amiga. 9 others are failures.
Here are 2 videos.
First one  is with the working one (debug/erasing/flashing).
The other is What I get with a bad CPLD (debug/erasing/flashing)
https://youtu.be/uMGF5WQTbJ0
https://youtu.be/LkSqpSJheZQ

I have opened a dispute on ALI /PayPal.
The supplier is my trusted Altera MAXII provider for PiSrorms and has been flawless.
But for those X9572XL it is not the same story :-(
Thanks again for your work and  this fast reply.
Br.
Cédric

LinuxJedi, 2022-04-02:
Things to check:
R1 - make sure it is a 1K resistor and not a higher value
R2 - make sure this is soldered correctly

Check pins 44, 11, 10, 9, 24 for solder bridges.

Assuming that is all good, then I would say that it is safe to assume the other CPLDs probably aren't good (or are at least not what is badged).

Sedrickgates, 2022-04-02:
Will do that today  ;-)
I have checked  solder bridges in production as I solder under microscope. Most board are looking that way.
 https://photos.app.goo.gl/Ty7gdCurFB7EDUAR7

Boards are JLCPCB FR4 150 type (thicker than 140)
For R value, true that I have not checked them. From What I have read I could even remove it as RPi would take care of the pull.

Thanks a million. Will try ASAP.

LinuxJedi, 2022-04-03:
Both R2 and R1 are pulls to communicate something to the Pi. R2 is pretty flexible in value but R1 has to be 1K because on the Pi this is an I2C pin, any higher and it doesn't pull. If you don't have R1 or it is too high a value then the Pi will think this is a legacy BBC board and misbehave.
The pulls that aren't required are for the buttons and are already removed on this design.

Sedrickgates, 2022-04-03:
I'll swap resistor. Value is between 600 and 1K on my cheap multimeter. I'll compare from the working one. Resistors are from same batch.
I'll report back.
Thk

LinuxJedi, 2022-04-03:
600-1K should be fine. I've seen a couple of people accidentally put a 4.7K there once or twice and it caused the firmware flashing menus to misbehave.

Off the top of my head, R2 tells the Pi there is a CPLD, without it the Pi will think it is a fixed-logic RGBtoHDMI board.

Sedrickgates, 2022-04-04:
I tried with 910ohm resistor to be sure my 1k serie would be bad. On multi 1k reads 1k and 910 ohm reads 910 as well.
Swapping did not fix issue so I can confirm CPLD is more than likely bad.
New batch of CPLD is coming soon.
Thanks for your help and all the details that I can use to troubleshoot the build.
My sincere respect to you!!!!

tyristori, 2022-06-20:
I've build over a 100 of these and I have two Zeros and one Zero 2 that have damaged GPIO that will cause this issue.

I was pulling my hair out the first time it happened before I figured out it was the GPIO.

LinuxJedi, 2022-06-20:
Ah, yes. I suspect a damaged GPIO could do this.

Sedrickgates, 2022-06-20:
In my case I use rose RPi for testing Pistorms with EMU68. GPIO are fine. I also ran GPIO test.
And a pulled CPLD from a working devboards works fine too.
Got the bad parts reimbursed
But thanks tor tour input.

LinuxJedi, 2022-11-27:
Closing this one for now.

Closed 2022-11-27.

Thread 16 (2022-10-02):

Other CPLD

shred, 2022-10-02:
The XC9572XL seems to be out of stock everywhere until 2024, at least for hobbyists.

Is there a way to redesign the adapters using a CPLD that is still available? (I don't know much about CPLDs, so I'm sorry if this is a really stupid question. :wink: )

LinuxJedi, 2022-10-02:
One builder has done a redesign to use the PLCC variant which had some availability. But I believe they are out of stock in most places now too. BGA variant is still available but it is not cheap (or easy to solder if you don't have the equipment to do it).

As for other brands of CPLD, it is possible, but the same supply issue pretty much exists and the flashing software would need to be updated accordingly (this may be more difficult).

shred, 2022-10-02:
Well, since the Raspberry Pi Zero is also out of stock (or sold at online auctions for 50€ or more), I guess we'll have to wait patiently.

Thank you for the answer. I will close this ticket.

Closed 2022-10-02.

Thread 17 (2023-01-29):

Video artifacting

mudmin, 2023-01-29:
Hi!  Thanks so much for this awesome project.

I'll be the first to say that I don't know what I don't know when it comes to Amiga stuff.  I've assembled a board and tested every pin for shorts with the mm, but I'm getting some artifacting on the screen. I'm guessing you've seen this before and might be able to point me in the right direction.  Here's a little 3 second clip.   https://photos.app.goo.gl/JEaZk1dhBtpuopQu9

LinuxJedi, 2023-01-29:
Hi @mudmin,

Did you run the auto-calibration in the RGBtoHDMI menu? It looks like it is just out of phase to me.

mudmin, 2023-01-29:
Oh my gosh. Thank you. I totally missed that and now it is perfect. You are a rockstar.

LinuxJedi, 2023-01-30:
Not a problem at all, glad it works for you now. Enjoy!

Closed 2023-01-29.

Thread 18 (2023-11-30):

BOM and POS for JLCPCB for Amiga 2000 2.2

JPT77, 2023-11-30:
[videoslotadapter-BOM-jlcpcb.xlsx](https://github.com/LinuxJedi/AmigaRGBtoHDMI/files/13516045/videoslotadapter-BOM-jlcpcb.xlsx)
[videoslotadapter-top.pos.jlcpcb.xlsx](https://github.com/LinuxJedi/AmigaRGBtoHDMI/files/13516046/videoslotadapter-top.pos.jlcpcb.xlsx)

Hi,
I created these files from KiCAD. You may put the files into the repo. I don't want to go through the Pull request procedure.
As they are, they are eaten by JLCPCB but not tested (produced). Some components have to be manually selected (eg the LED resistor does not have a value and the CPLD is currently out of stock, use the industrial version for double price).

They are for SMD parts only. As THT parts are better soldered at home.

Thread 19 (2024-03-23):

Question on usage of RGB2HDMI adapter

slappy32, 2024-03-23:
Hello,
I have got three questions.
I own an Amiga 1200 built into a Mikronik tower case, Zorro2 expansion board and video slot adapter installed,
so that it candle GFX boards. I have a Peggy plus Mpeg decoder card in that slot, but I rarely use it.

1. Does your RGBtoHDMI adapter also convert AGA screenmodes like DblPAL correctly to HDMI?
My WB 3.1 is running in my prefered DblPAL mode while games started with WHDload will switch back to PAL mode.
PAL is also used for boot-menu  and while booting.
I already own an industrial LCD monitor (VGA slot) that can handle all Amiga screemodes, but it does have a nasty unsharp or
blur-effect with horizontally scrolling games. Or as soon as I move the warrior to the left or right,  e.g. in the game Turrican.
So, my idea is to try out your RGBtoHDMI adapter with a standard LCD monitor or TV with HDMI input.
I have discovered it ready to use on Ebay, but the seller Sordan electronic deactivated sending messages/questions.

2. Did you try out your adapter with A500+ ECS productivity modes?

3. Can a wrong Amiga screenmode e.g. DblPal, Super72 or VGA damage your RBGtoHDMI adapter?

I say thanks for your reply in advance.

Greetings,
slappy32

LinuxJedi, 2024-03-23:
Hello! I will try to answer them as best I can.

1. No, it will never be able to support AGA modes. Even if the CPLD was switched to one that would take the extra video data lines, the Pi does not have enough IO pins to take it. This means it would need to be multiplexed and the Pi's GPIO is not fast enough to do multiplexing of video data. That being said, the PiStorm project has a sub-project in development that can a) do AGA RGBtoHDMI itself, without a Pi or b) inject the AGA data to a Pi via the camera port, which is intended to be used to mix with the RTG for PiStorm.
2. Whilst I haven't tried it, the latest beta supports ECS modes: https://github.com/IanSB/RGBtoHDMI/releases
3. No, it won't damage it, if it is not supported then it just won't be able to lock on to the picture properly.

Hope that helps.

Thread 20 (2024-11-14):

CPLD Recovery Menu - Confirm programming in single button mode not possible

hudecitydave, 2024-11-14:
Hi there!

I have my litte solderjob done here and got my CPLD Recovery menu presented now. So far so good. I copied the config files and profile to their positions, and I also checked single_button_mode=1 in Default. So should be happy.

But...

I am able to surf the whole menu behind "return", can set settings short-klicking to select things and long clicking to confirm and so on. working fine.

But only on the point  --Current: BLANK: Confirm?--

I get stuck.

If I short click, I leave the selection, and go from RGB Item to next YUV Item (as expected).

If I long click to accept programming, while holding button status flashes between "Confirm" and "Select Correct CPLD".
Feels like it does not take a long click for OK, instead it fires instant shorts in a row or something.

Again - the whole one-button function is working well, only the one point confirming the programming get stuck.

What am I doing wrong here?

Thank you so much!

kennyevo, 2025-05-06:
Well, I'm having the same issue, have you solved it?

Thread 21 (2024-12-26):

Screen garbadges with  copy on A1000 accelerated @28mhz

lolof70, 2024-12-26:
Hi,

I have an accelerator in my A1000 switchable from 7mhz to 28mhz.
All seems to working fine, it only has an issue so far only with xcopy…

at 28mhz, the xcopy screen as a lot of bad/wrong pixels.
At 7mhz, all is perfectly fine.

At 7mhz and 28mhz with a classic dsub rgb Amiga video cable or with a D520, all is fine.
Is there something I can do to solve this 28mhz problem ? (Except switch to 7mhz 😀 )
Here screenshot.

than you.

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

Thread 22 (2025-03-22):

New version feature (audio)

Vanles, 2025-03-22:
Hello,
first off, great project – really well done!

For a future version, would it be possible to include the Amiga's analog or digital audio directly in the HDMI stream? For instance, by providing suitable solder points on the board and adding a circuit that converts the analog signal into a digital audio signal and outputs it directly from the board? Would that be technically feasible?

Thanks
Marco

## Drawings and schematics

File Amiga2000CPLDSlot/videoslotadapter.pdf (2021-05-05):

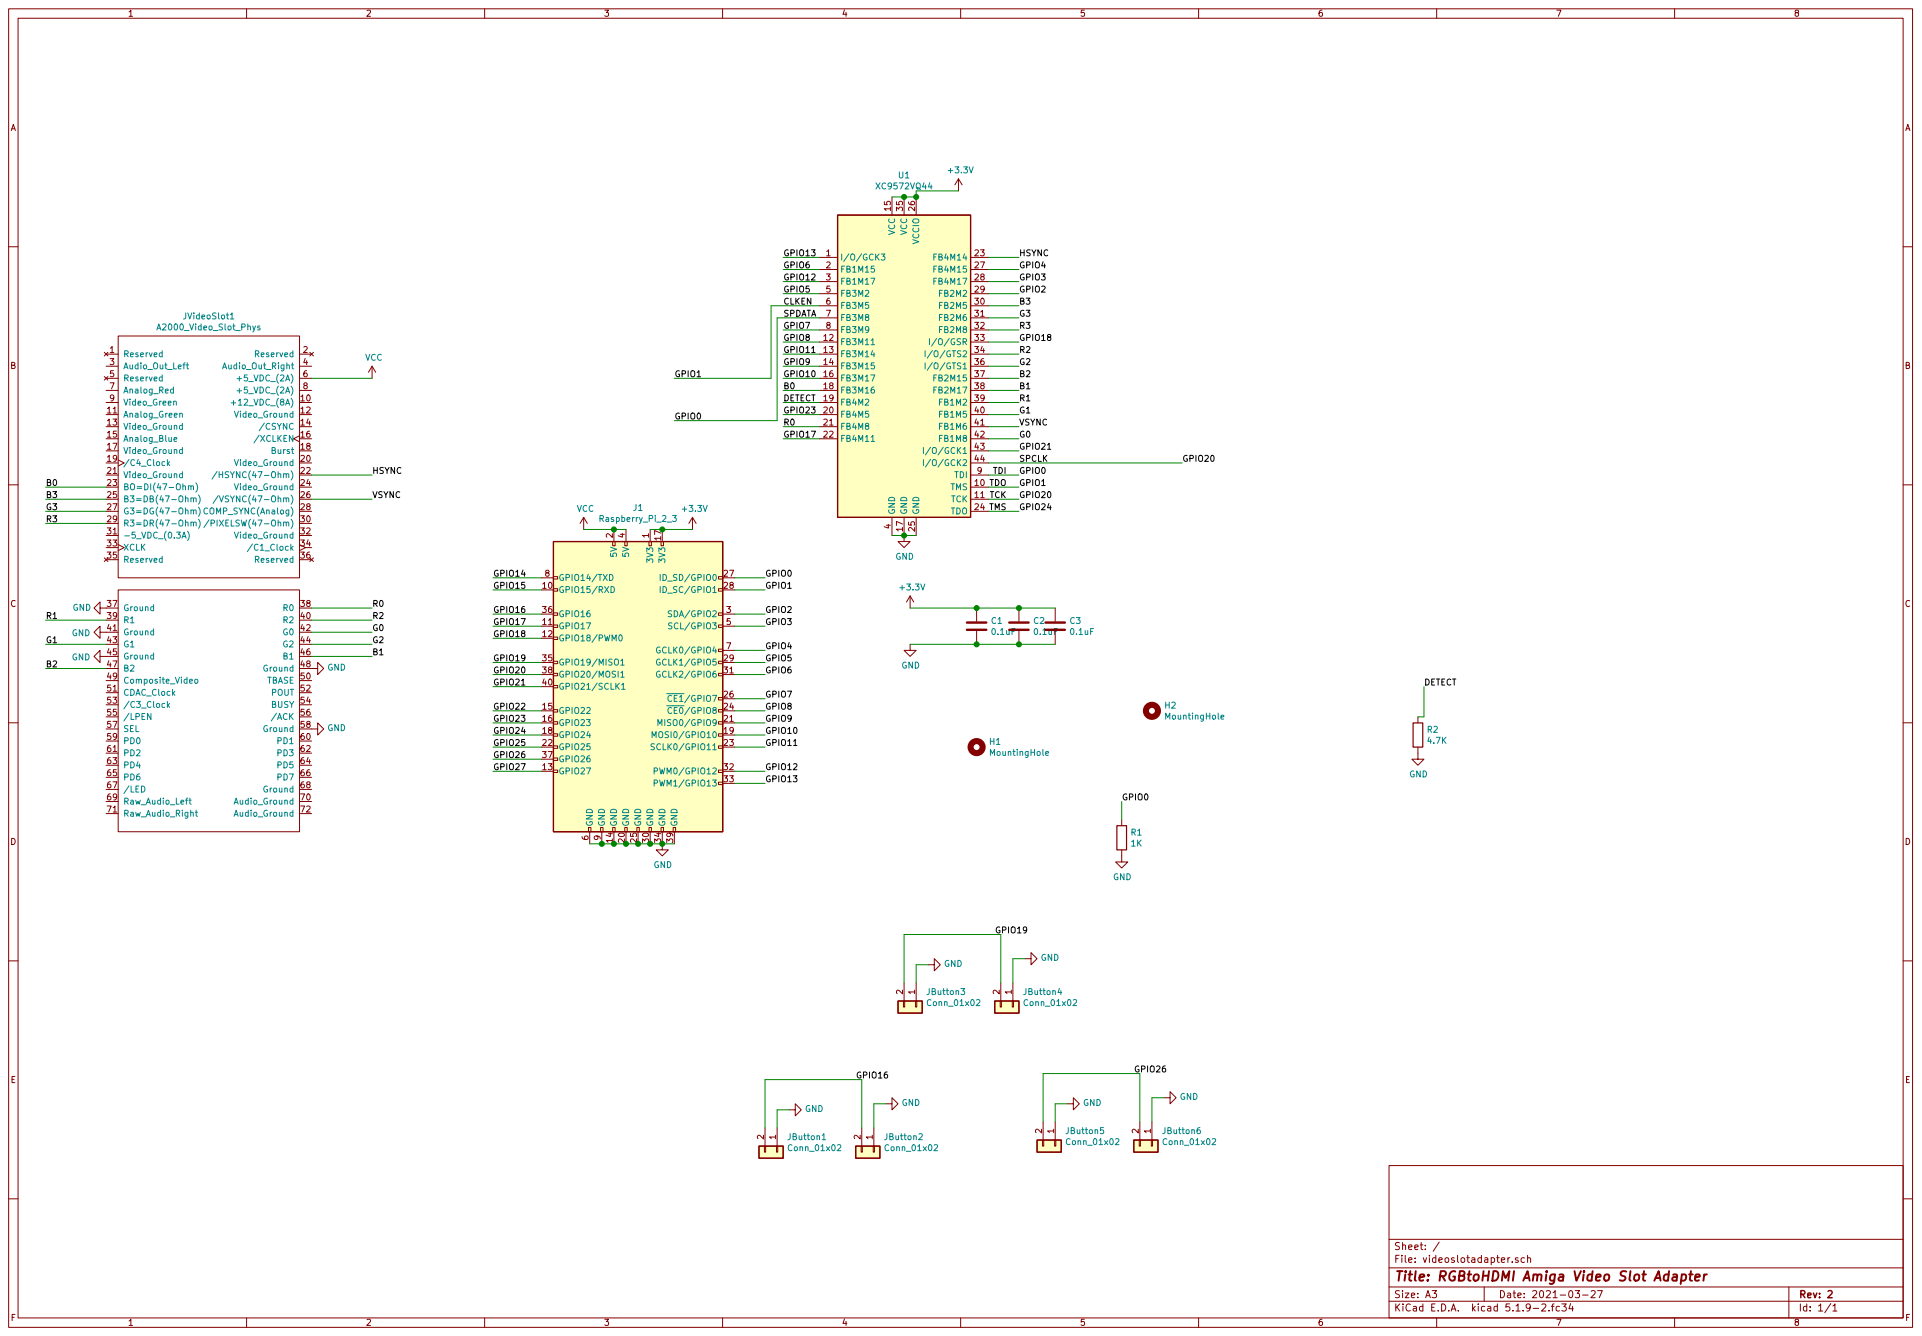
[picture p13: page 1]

VCC GND GND GND GND

File: videoslotadapter.sch Sheet: / GND

Id: 1/1 Title: RGBtoHDMI Amiga Video Slot Adapter

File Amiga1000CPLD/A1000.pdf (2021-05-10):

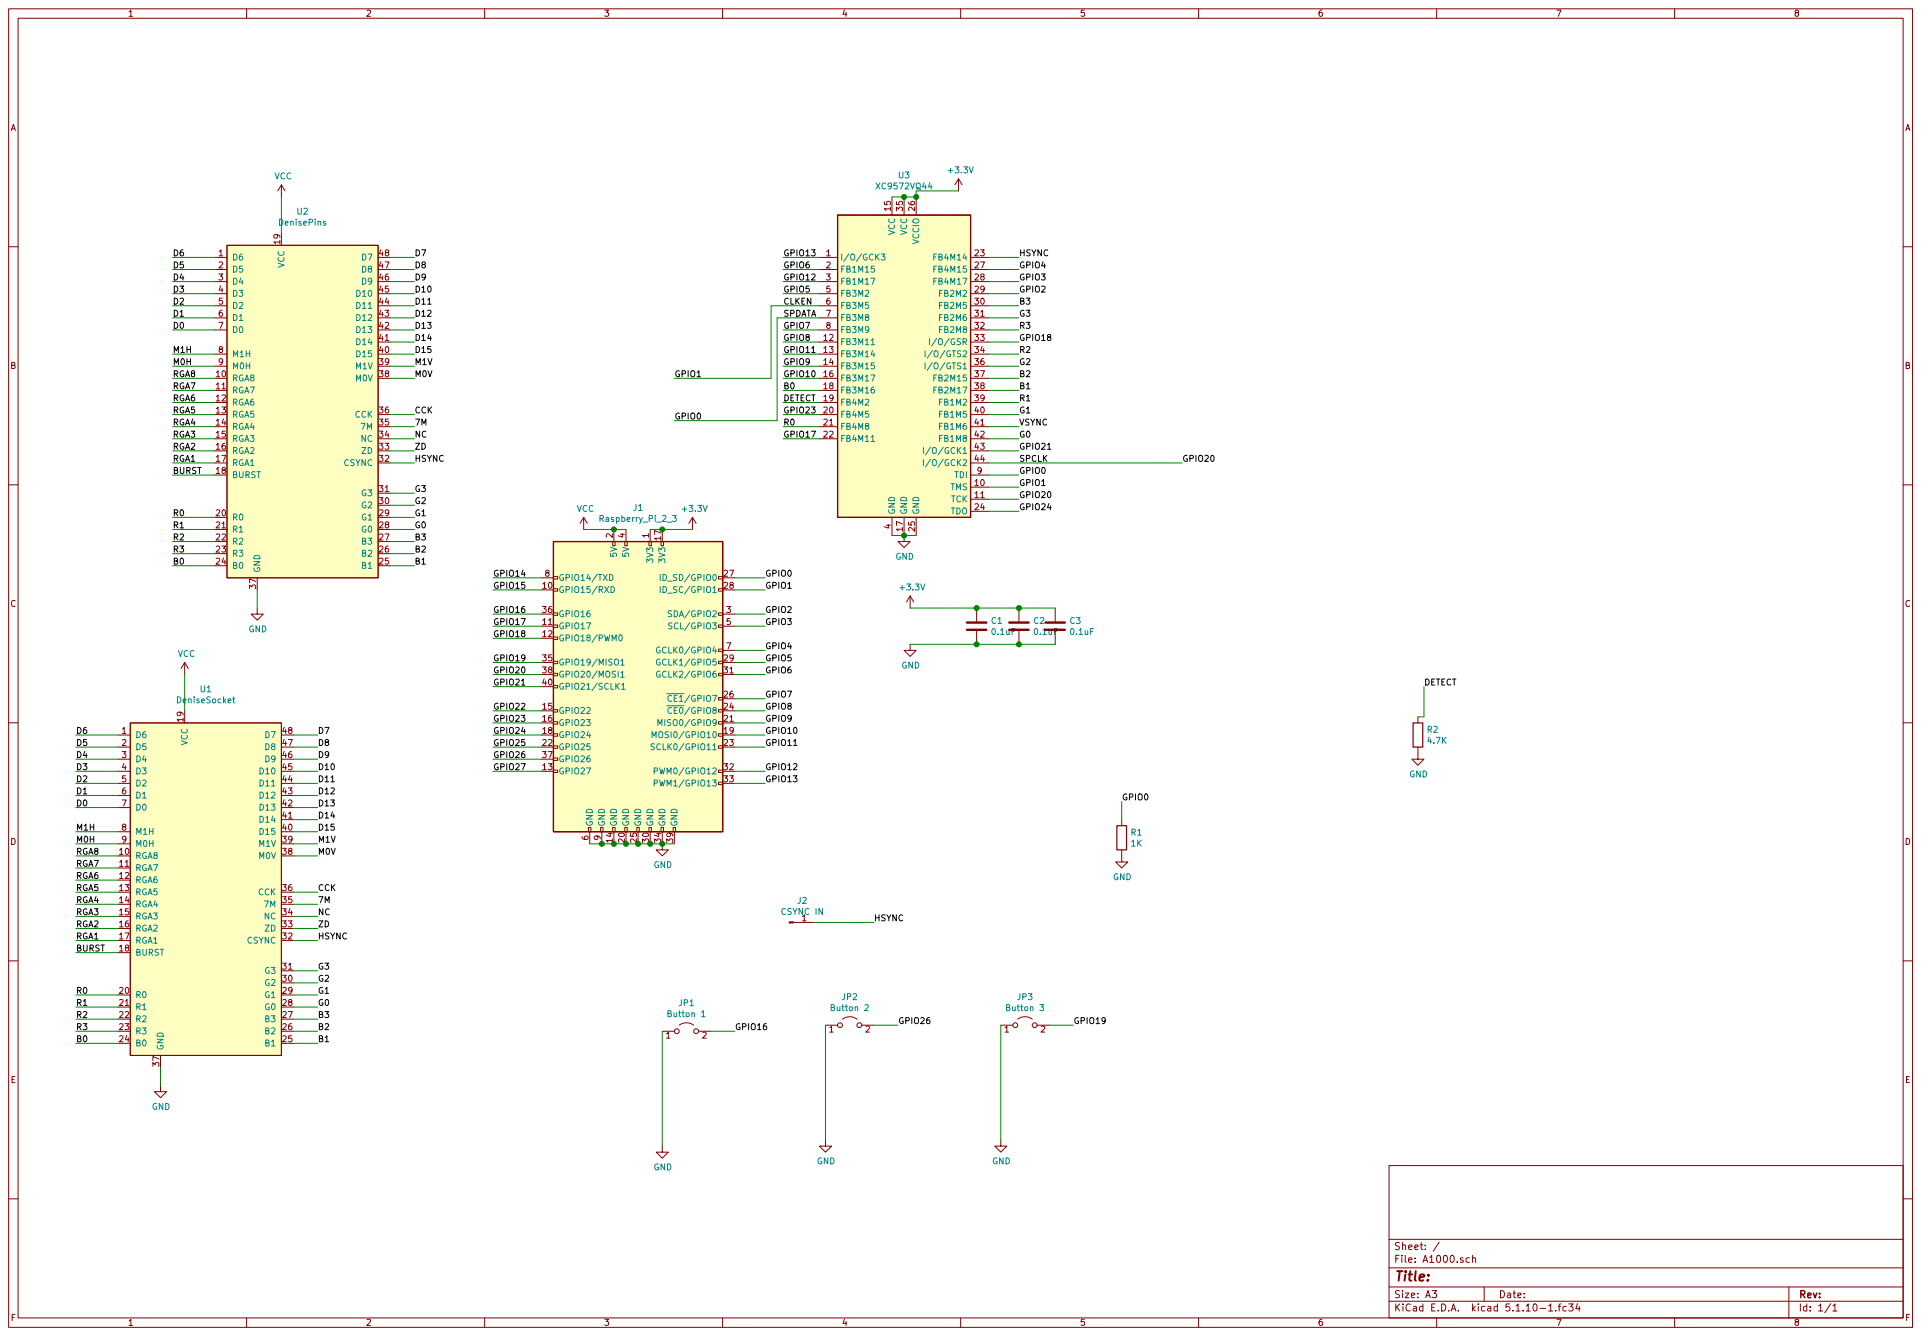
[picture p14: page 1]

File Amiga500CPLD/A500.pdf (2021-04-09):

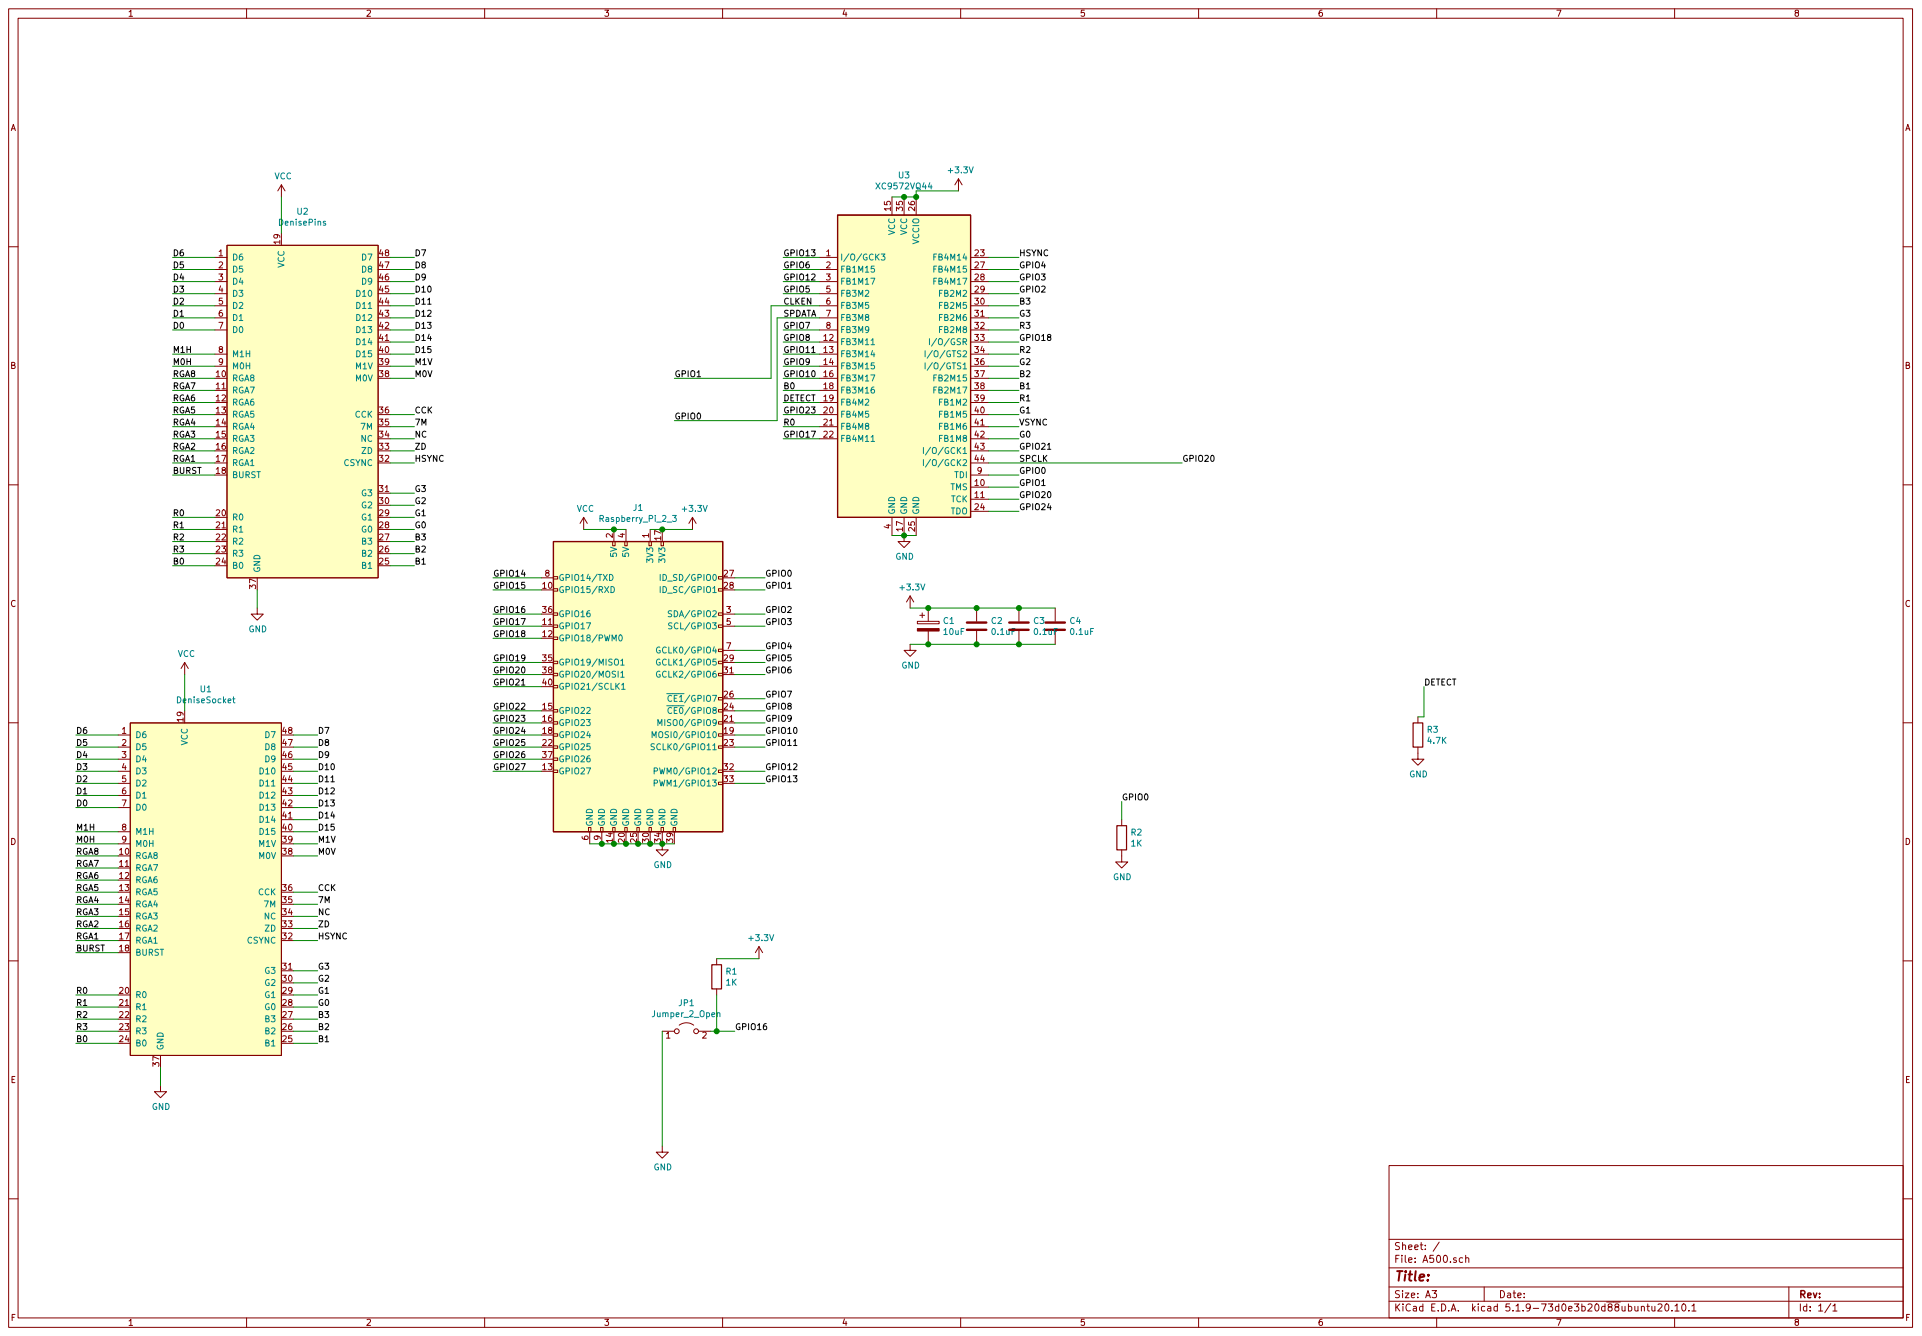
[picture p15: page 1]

Id: 1/1 Title: File: A500.sch Sheet: /

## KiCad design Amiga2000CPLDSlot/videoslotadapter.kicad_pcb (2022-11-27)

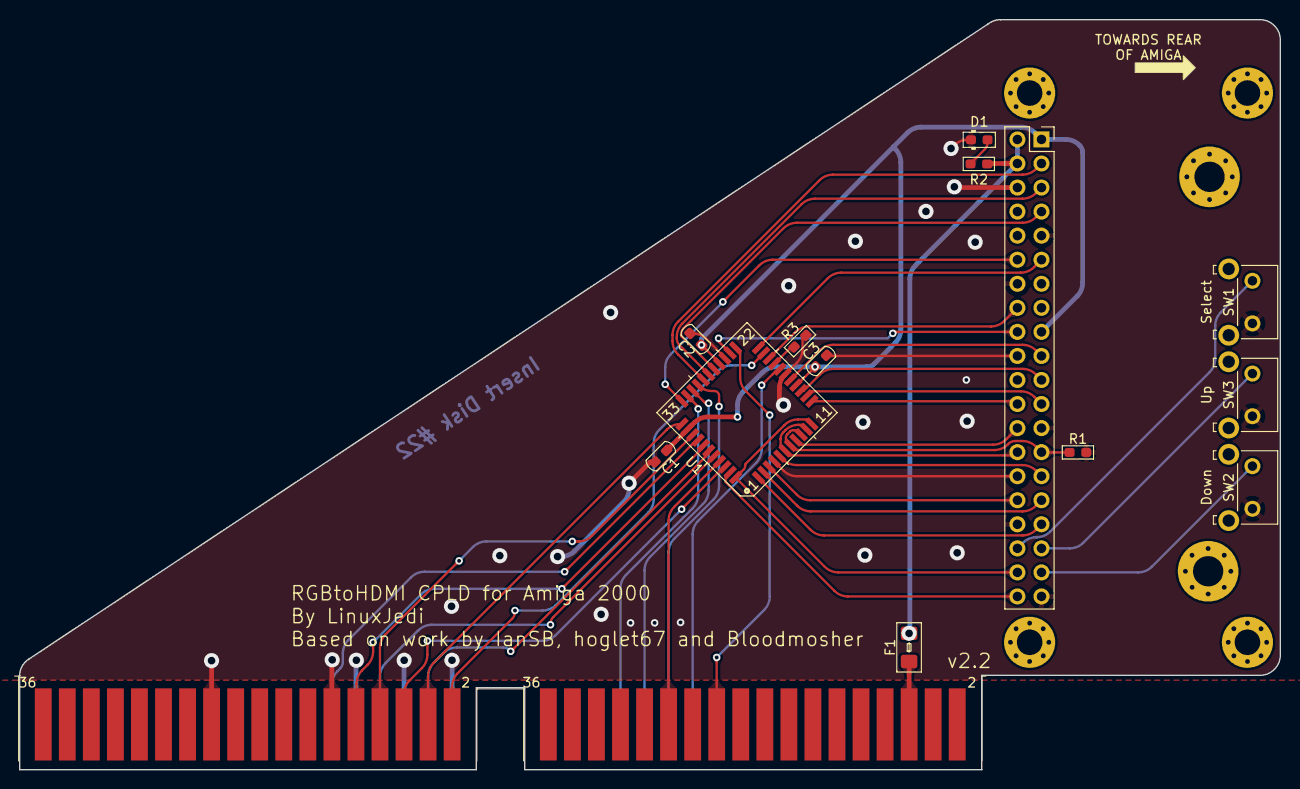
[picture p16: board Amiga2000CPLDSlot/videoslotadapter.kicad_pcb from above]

Board: 2 copper layers, 133.1 x 79.2 mm, 20 parts (0 on the bottom side), 43 nets.

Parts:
C1, C2, C3: 0.1uF; C_0603_1608Metric_Pad1.08x0.95mm
D1: LED; D_0603_1608Metric_Pad1.05x0.95mm
F1: 500mA; Fuse_1206_3216Metric_Pad1.42x1.75mm_BigPads
H1, H2, H3, H4: MountingHole; MountingHole_2.7mm_M2.5_Pad_Via
H5, H6: MountingHole; MountingHole_3.2mm_M3_Pad_Via
J1: Raspberry_Pi_2_3; PinSocket_2x20_P2.54mm_Vertical
JVideoSlot1: A2000_Video_Slot_Phys; A2000_Video_Slot
R1: 1K; R_0603_1608Metric_Pad1.05x0.95mm_HandSolder
R2: R; R_0603_1608Metric_Pad1.05x0.95mm_HandSolder
R3: 4.7K; R_0603_1608Metric_Pad1.05x0.95mm_HandSolder
SW1: Select; SW_Tactile_SKHH_Angled
SW2: Down; SW_Tactile_SKHH_Angled
SW3: Up; SW_Tactile_SKHH_Angled
U1: XC9572VQ44; TQFP-44_10x10mm_P0.8mm

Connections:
+3V3: C1.1, C2.1, C3.1, J1.1 (3V3), J1.17 (3V3), U1.15 (VCC), U1.26 (VCCIO), U1.35 (VCC)
+5V: F1.2, J1.2 (5V), J1.4 (5V), R2.2
/B0: JVideoSlot1.23 (BO=DI(47-Ohm)), U1.18 (FB3M16)
/B1: JVideoSlot1.46 (B1), U1.38 (FB2M17)
/B2: JVideoSlot1.47 (B2), U1.37 (FB2M15)
/B3: JVideoSlot1.25 (B3=DB(47-Ohm)), U1.30 (FB2M5)
/CLKEN: J1.28 (ID_SC/GPIO1), U1.6 (FB3M5), U1.10 (TMS)
/DETECT: R3.1, U1.19 (FB4M2)
/G0: JVideoSlot1.42 (G0), U1.42 (FB1M8)
/G1: JVideoSlot1.43 (G1), U1.40 (FB1M5)
/G2: JVideoSlot1.44 (G2), U1.36 (I/O/GTS1)
/G3: JVideoSlot1.27 (G3=DG(47-Ohm)), U1.31 (FB2M6)
/GPIO0: J1.27 (ID_SD/GPIO0), R1.1, U1.7 (FB3M8), U1.9 (TDI)
/GPIO2: J1.3 (SDA/GPIO2), U1.29 (FB2M2)
/GPIO3: J1.5 (SCL/GPIO3), U1.28 (FB4M17)
/GPIO4: J1.7 (GCLK0/GPIO4), U1.27 (FB4M15)
/GPIO5: J1.29 (GCLK1/GPIO5), U1.5 (FB3M2)
/GPIO6: J1.31 (GCLK2/GPIO6), U1.2 (FB1M15)
/GPIO7: J1.26 (~CE1/GPIO7), U1.8 (FB3M9)
/GPIO8: J1.24 (~CE0/GPIO8), U1.12 (FB3M11)
/GPIO9: J1.21 (MISO0/GPIO9), U1.14 (FB3M15)
/GPIO10: J1.19 (MOSI0/GPIO10), U1.16 (FB3M17)
/GPIO11: J1.23 (SCLK0/GPIO11), U1.13 (FB3M14)
/GPIO12: J1.32 (PWM0/GPIO12), U1.3 (FB1M17)
/GPIO13: J1.33 (PWM1/GPIO13), U1.1 (I/O/GCK3)
/GPIO16: J1.36 (GPIO16), SW1.1
/GPIO17: J1.11 (GPIO17), U1.22 (FB4M11)
/GPIO18: J1.12 (GPIO18/PWM0), U1.33 (I/O/GSR)
/GPIO19: J1.35 (GPIO19/MISO1), SW3.1
/GPIO20: J1.38 (GPIO20/MOSI1), U1.11 (TCK), U1.44 (I/O/GCK2)
/GPIO21: J1.40 (GPIO21/SCLK1), U1.43 (I/O/GCK1)
/GPIO23: J1.16 (GPIO23), U1.20 (FB4M5)
/GPIO24: J1.18 (GPIO24), U1.24 (TDO)
/GPIO26: J1.37 (GPIO26), SW2.1
/HSYNC: JVideoSlot1.22 (/HSYNC(47-Ohm)), U1.23 (FB4M14)
/R0: JVideoSlot1.38 (R0), U1.21 (FB4M8)
/R1: JVideoSlot1.39 (R1), U1.39 (FB1M2)
/R2: JVideoSlot1.40 (R2), U1.34 (I/O/GTS2)
/R3: JVideoSlot1.29 (R3=DR(47-Ohm)), U1.32 (FB2M8)
/VSYNC: JVideoSlot1.26 (/VSYNC(47-Ohm)), U1.41 (FB1M6)
GND: C1.2, C2.2, C3.2, D1.1 (K), J1.6 (GND), J1.9 (GND), J1.14 (GND), J1.20 (GND), J1.25 (GND), J1.30 (GND), J1.34 (GND), J1.39 (GND), JVideoSlot1.37 (Ground), JVideoSlot1.41 (Ground), JVideoSlot1.45 (Ground), JVideoSlot1.48 (Ground), JVideoSlot1.58 (Ground), R1.2, R3.2, SW1.2, SW2.2, SW3.2, U1.4 (GND), U1.17 (GND), U1.25 (GND)
unnamed: D1.2 (A), R2.1
VCC: F1.1, JVideoSlot1.6 (+5_VDC_(2A))

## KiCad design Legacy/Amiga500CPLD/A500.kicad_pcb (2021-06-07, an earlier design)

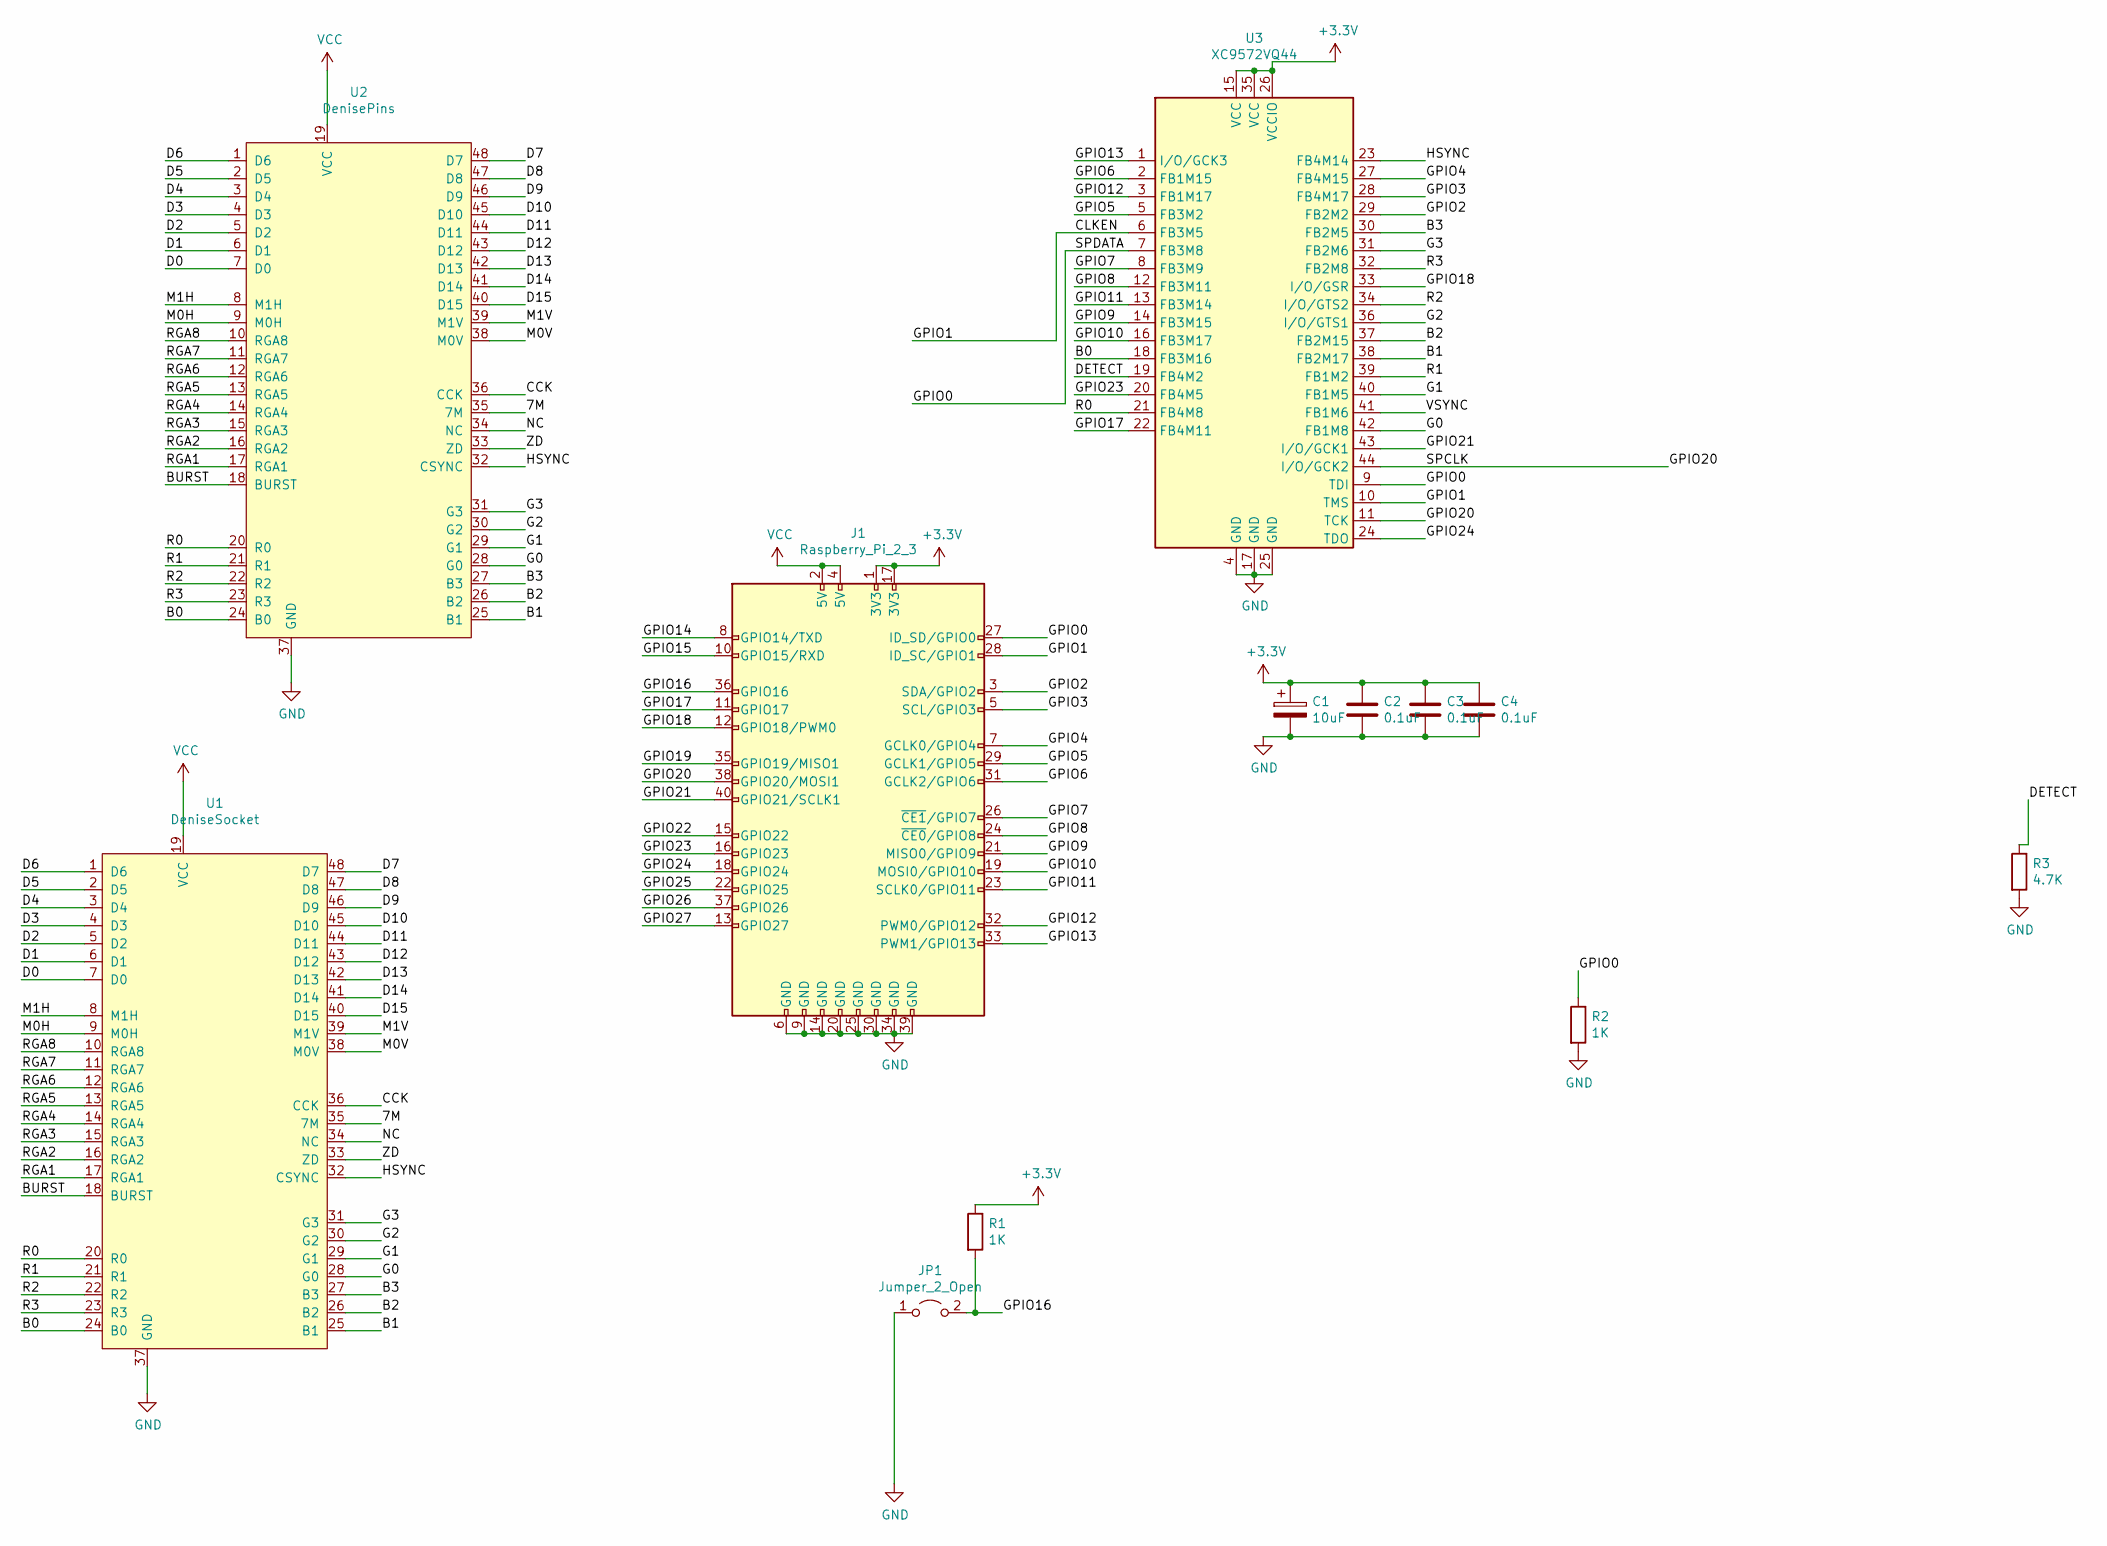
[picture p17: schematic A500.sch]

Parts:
C1: 10uF; C_1206_3216Metric_Pad1.33x1.80mm_HandSolder
C2, C3, C4: 0.1uF; C_0603_1608Metric_Pad1.08x0.95mm_HandSolder
J1: Raspberry_Pi_2_3; PinSocket_2x20_P2.54mm_Vertical
JP1: Jumper_2_Open; PinHeader_1x02_P2.54mm_Horizontal
R1, R2: 1K; R_0603_1608Metric_Pad0.98x0.95mm_HandSolder
R3: 4.7K; R_0603_1608Metric_Pad0.98x0.95mm_HandSolder
U1: DeniseSocket; DIP-48_W15.24mm_Socket
U2: DenisePins; DIP-48_pins
U3: XC9572VQ44; TQFP-44_10x10mm_P0.8mm

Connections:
+3V3: C1.1, C2.1, C3.1, C4.1, J1.1 (3V3), J1.17 (3V3), R1.1, U3.15 (VCC), U3.26 (VCCIO), U3.35 (VCC)
/7M: U1.35 (7M), U2.35 (7M)
/B0: U1.24 (B0), U2.24 (B0), U3.18 (FB3M16)
/B1: U1.25 (B1), U2.25 (B1), U3.38 (FB2M17)
/B2: U1.26 (B2), U2.26 (B2), U3.37 (FB2M15)
/B3: U1.27 (B3), U2.27 (B3), U3.30 (FB2M5)
/BURST: U1.18 (BURST), U2.18 (BURST)
/CCK: U1.36 (CCK), U2.36 (CCK)
/CLKEN: J1.28 (ID_SC/GPIO1), U3.6 (FB3M5), U3.10 (TMS)
/D0: U1.7 (D0), U2.7 (D0)
/D1: U1.6 (D1), U2.6 (D1)
/D2: U1.5 (D2), U2.5 (D2)
/D3: U1.4 (D3), U2.4 (D3)
/D4: U1.3 (D4), U2.3 (D4)
/D5: U1.2 (D5), U2.2 (D5)
/D6: U1.1 (D6), U2.1 (D6)
/D7: U1.48 (D7), U2.48 (D7)
/D8: U1.47 (D8), U2.47 (D8)
/D9: U1.46 (D9), U2.46 (D9)
/D10: U1.45 (D10), U2.45 (D10)
/D11: U1.44 (D11), U2.44 (D11)
/D12: U1.43 (D12), U2.43 (D12)
/D13: U1.42 (D13), U2.42 (D13)
/D14: U1.41 (D14), U2.41 (D14)
/D15: U1.40 (D15), U2.40 (D15)
/DETECT: R3.1, U3.19 (FB4M2)
/G0: U1.28 (G0), U2.28 (G0), U3.42 (FB1M8)
/G1: U1.29 (G1), U2.29 (G1), U3.40 (FB1M5)
/G2: U1.30 (G2), U2.30 (G2), U3.36 (I/O/GTS1)
/G3: U1.31 (G3), U2.31 (G3), U3.31 (FB2M6)
/GPIO0: J1.27 (ID_SD/GPIO0), R2.1, U3.7 (FB3M8), U3.9 (TDI)
/GPIO2: J1.3 (SDA/GPIO2), U3.29 (FB2M2)
/GPIO3: J1.5 (SCL/GPIO3), U3.28 (FB4M17)
/GPIO4: J1.7 (GCLK0/GPIO4), U3.27 (FB4M15)
/GPIO5: J1.29 (GCLK1/GPIO5), U3.5 (FB3M2)
/GPIO6: J1.31 (GCLK2/GPIO6), U3.2 (FB1M15)
/GPIO7: J1.26 (~CE1~/GPIO7), U3.8 (FB3M9)
/GPIO8: J1.24 (~CE0~/GPIO8), U3.12 (FB3M11)
/GPIO9: J1.21 (MISO0/GPIO9), U3.14 (FB3M15)
/GPIO10: J1.19 (MOSI0/GPIO10), U3.16 (FB3M17)
/GPIO11: J1.23 (SCLK0/GPIO11), U3.13 (FB3M14)
/GPIO12: J1.32 (PWM0/GPIO12), U3.3 (FB1M17)
/GPIO13: J1.33 (PWM1/GPIO13), U3.1 (I/O/GCK3)
/GPIO14: J1.8 (GPIO14/TXD)
/GPIO15: J1.10 (GPIO15/RXD)
/GPIO16: J1.36 (GPIO16), JP1.2 (B), R1.2
/GPIO17: J1.11 (GPIO17), U3.22 (FB4M11)
/GPIO18: J1.12 (GPIO18/PWM0), U3.33 (I/O/GSR)
/GPIO19: J1.35 (GPIO19/MISO1)
/GPIO20: J1.38 (GPIO20/MOSI1), U3.11 (TCK), U3.44 (I/O/GCK2)
/GPIO21: J1.40 (GPIO21/SCLK1), U3.43 (I/O/GCK1)
/GPIO22: J1.15 (GPIO22)
/GPIO23: J1.16 (GPIO23), U3.20 (FB4M5)
/GPIO24: J1.18 (GPIO24), U3.24 (TDO)
/GPIO25: J1.22 (GPIO25)
/GPIO26: J1.37 (GPIO26)
/GPIO27: J1.13 (GPIO27)
/HSYNC: U1.32 (CSYNC), U2.32 (CSYNC), U3.23 (FB4M14)
/M0H: U1.9 (M0H), U2.9 (M0H)
/M0V: U1.38 (M0V), U2.38 (M0V)
/M1H: U1.8 (M1H), U2.8 (M1H)
/M1V: U1.39 (M1V), U2.39 (M1V)
/NC: U1.34 (NC), U2.34 (NC)
/R0: U1.20 (R0), U2.20 (R0), U3.21 (FB4M8)
/R1: U1.21 (R1), U2.21 (R1), U3.39 (FB1M2)
/R2: U1.22 (R2), U2.22 (R2), U3.34 (I/O/GTS2)
/R3: U1.23 (R3), U2.23 (R3), U3.32 (FB2M8)
/RGA1: U1.17 (RGA1), U2.17 (RGA1)
/RGA2: U1.16 (RGA2), U2.16 (RGA2)
/RGA3: U1.15 (RGA3), U2.15 (RGA3)
/RGA4: U1.14 (RGA4), U2.14 (RGA4)
/RGA5: U1.13 (RGA5), U2.13 (RGA5)
/RGA6: U1.12 (RGA6), U2.12 (RGA6)
/RGA7: U1.11 (RGA7), U2.11 (RGA7)
/RGA8: U1.10 (RGA8), U2.10 (RGA8)
/VSYNC: U3.41 (FB1M6)
/ZD: U1.33 (ZD), U2.33 (ZD)
GND: C1.2, C2.2, C3.2, C4.2, J1.6 (GND), J1.9 (GND), J1.14 (GND), J1.20 (GND), J1.25 (GND), J1.30 (GND), J1.34 (GND), J1.39 (GND), JP1.1 (A), R2.2, R3.2, U1.37 (GND), U2.37 (GND), U3.4 (GND), U3.17 (GND), U3.25 (GND)
VCC: J1.2 (5V), J1.4 (5V), U1.19 (VCC), U2.19 (VCC)

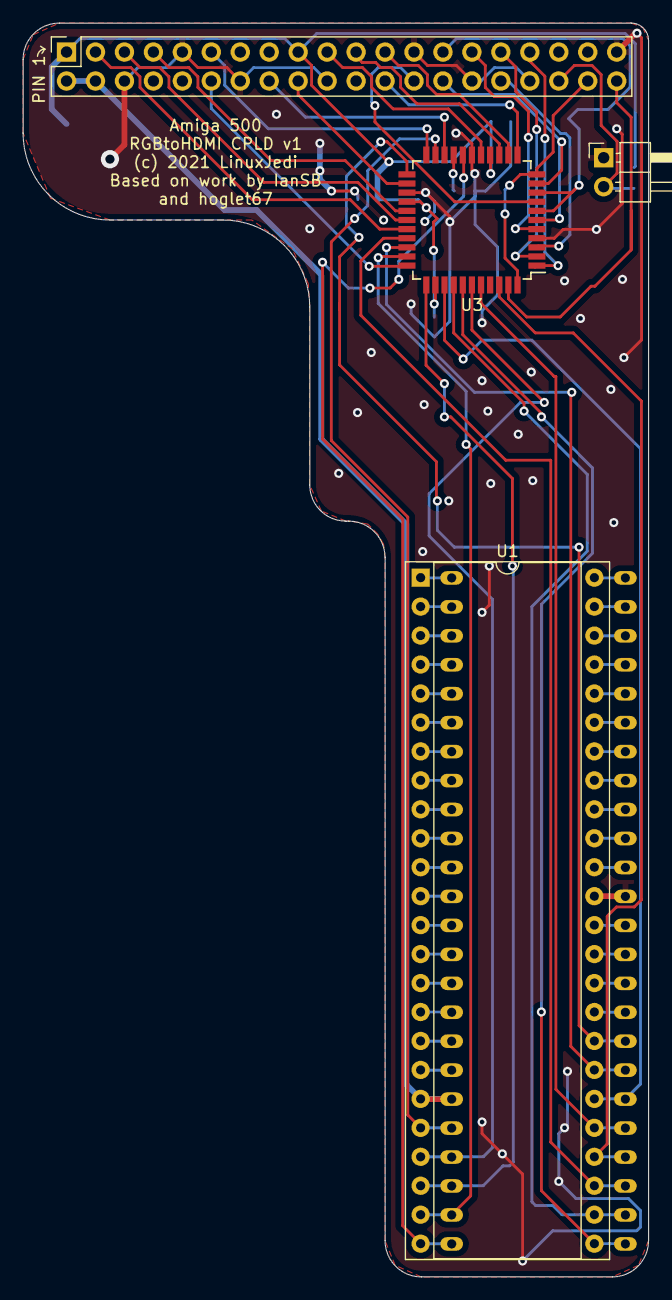
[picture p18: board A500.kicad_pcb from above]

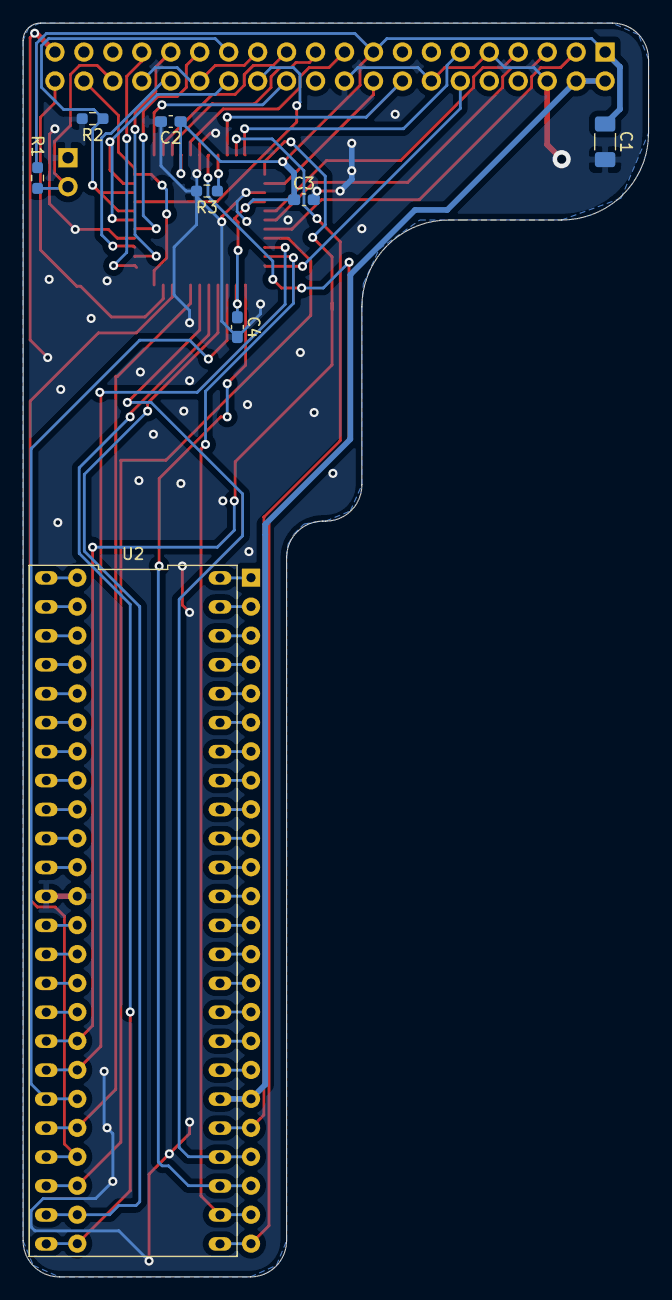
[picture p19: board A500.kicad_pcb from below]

Board: 2 copper layers, 54.9 x 110.0 mm, 12 parts (8 on the bottom side), 71 nets.

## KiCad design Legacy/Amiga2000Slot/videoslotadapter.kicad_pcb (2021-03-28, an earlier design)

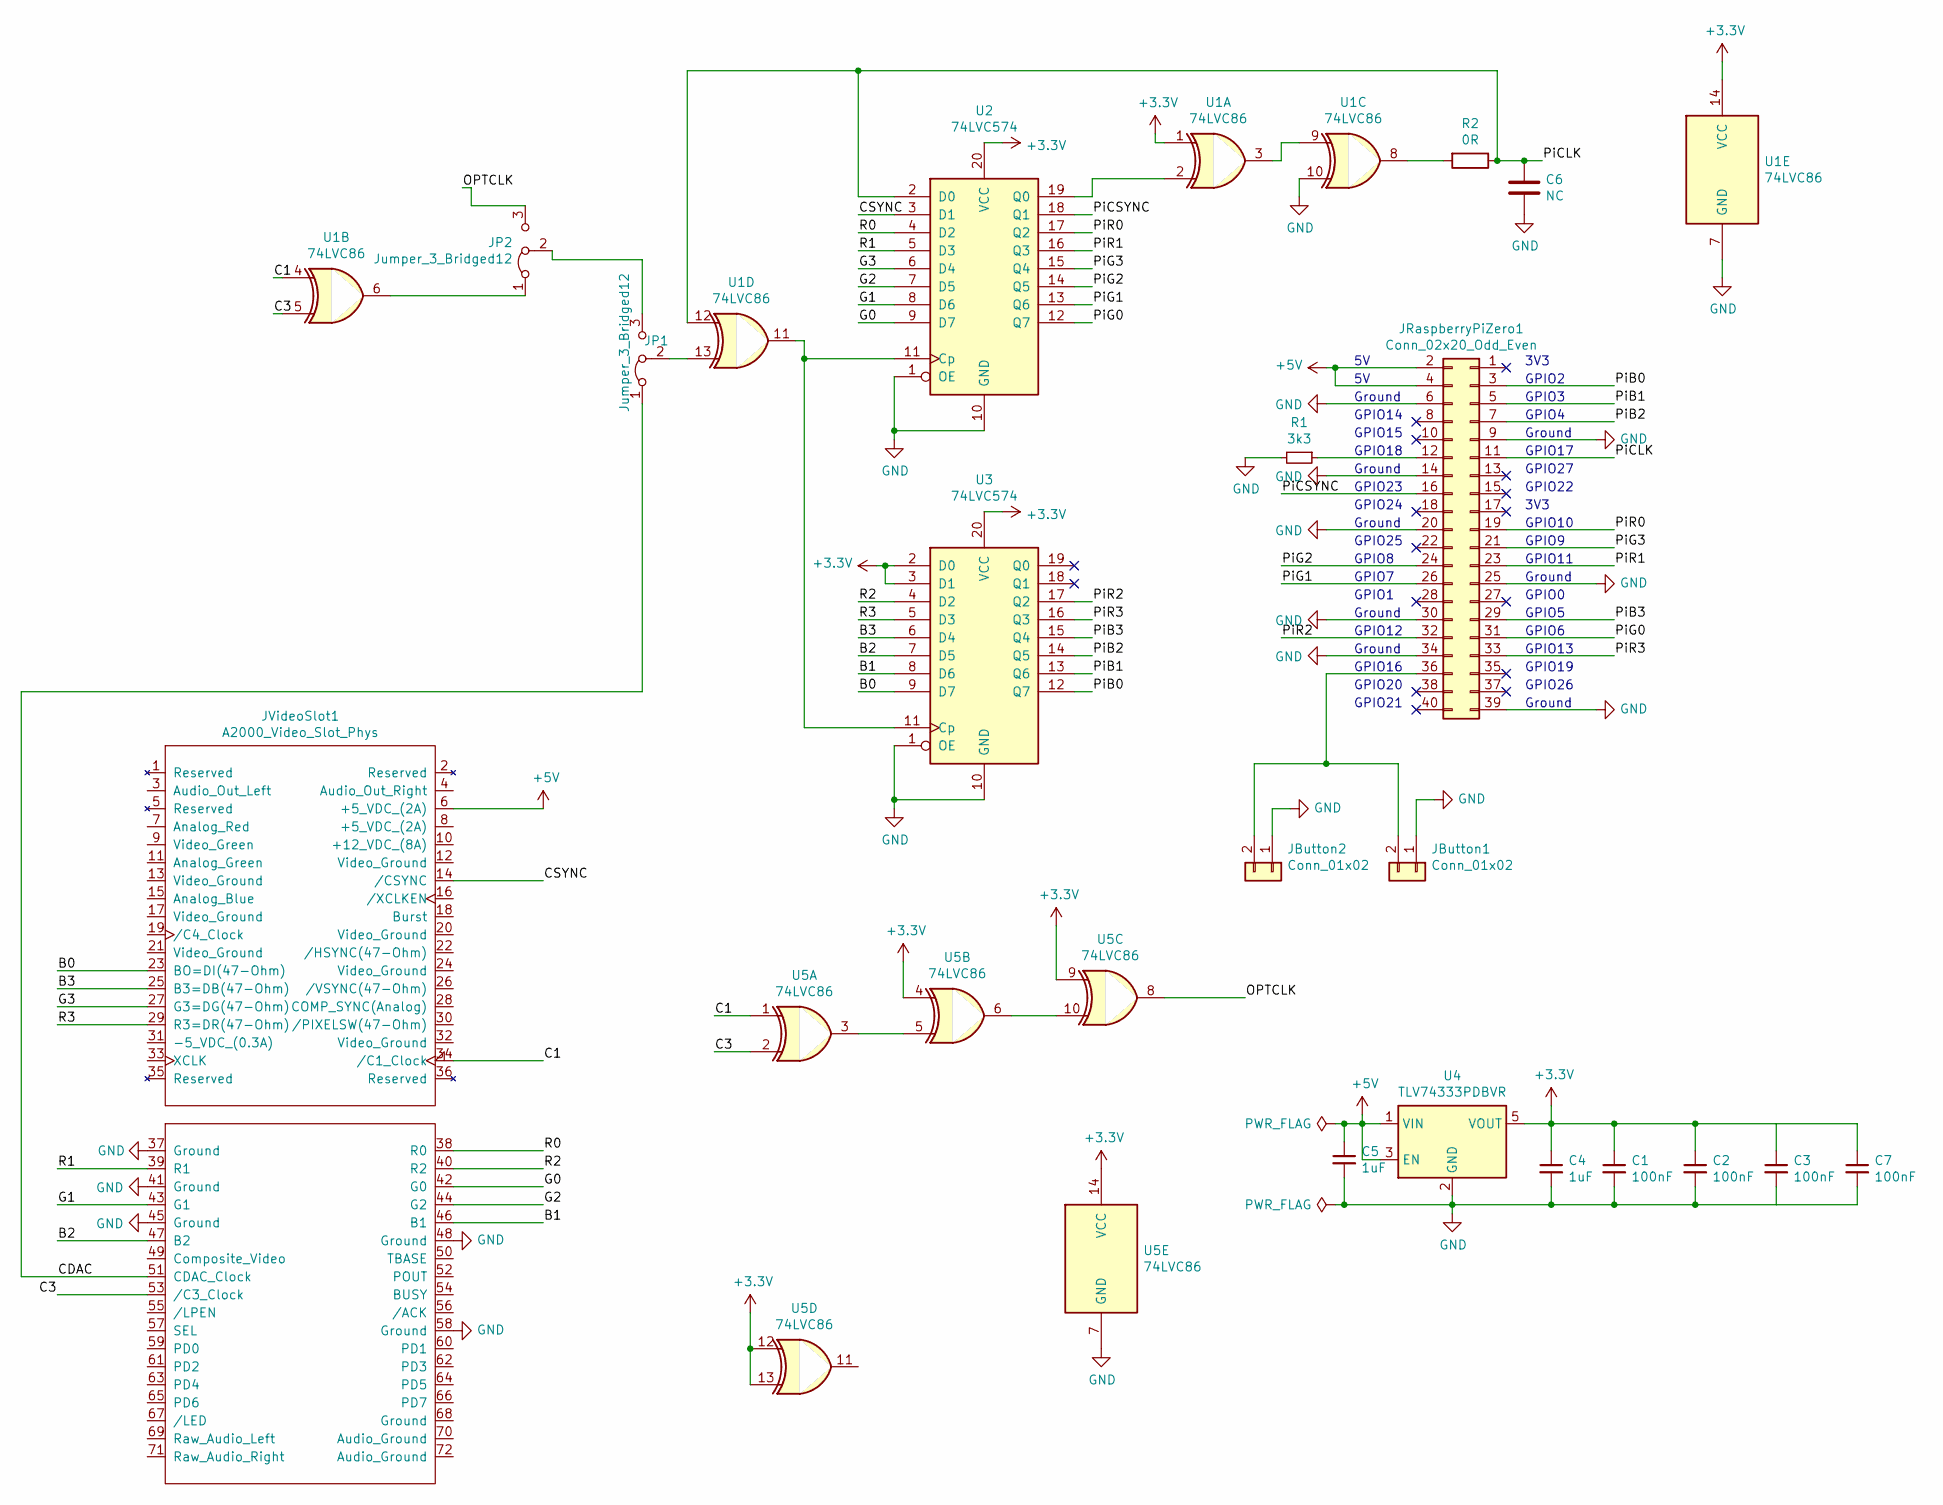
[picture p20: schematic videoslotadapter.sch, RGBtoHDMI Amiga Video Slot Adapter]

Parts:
C1, C2, C3, C7: 100nF; C_0603_1608Metric_Pad1.08x0.95mm_HandSolder
C4, C5: 1uF; C_0805_2012Metric_Pad1.18x1.45mm_HandSolder
C6: NC; C_0603_1608Metric_Pad1.08x0.95mm_HandSolder
JButton1, JButton2: Conn_01x02; PinHeader_1x02_P2.54mm_Horizontal
JP1: Jumper_3_Bridged12; PinHeader_1x03_P2.54mm_Horizontal
JP2: Jumper_3_Bridged12; SolderJumper-3_P1.3mm_Open_Pad1.0x1.5mm
JRaspberryPiZero1: Conn_02x20_Odd_Even; PinSocket_2x20_P2.54mm_Vertical
JVideoSlot1: A2000_Video_Slot_Phys; A2000_Video_Slot
R1: 3k3; R_0805_2012Metric_Pad1.20x1.40mm_HandSolder
R2: 0R; R_0603_1608Metric_Pad0.98x0.95mm_HandSolder
U1, U5: 74LVC86; TSSOP-14_4.4x5mm_P0.65mm
U2, U3: 74LVC574; TSSOP-20_4.4x6.5mm_P0.65mm
U4: TLV74333PDBVR; SOT-23-5_HandSoldering

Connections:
+3V3: C1.1, C2.1, C3.1, C4.1, C7.1, U1.1, U1.14 (VCC), U2.20 (VCC), U3.2 (D0), U3.3 (D1), U3.20 (VCC), U4.5 (VOUT), U5.4, U5.9, U5.12, U5.13, U5.14 (VCC)
+5V: C5.1, JRaspberryPiZero1.2, JRaspberryPiZero1.4, JVideoSlot1.6 (+5_VDC_(2A)), U4.1 (VIN), U4.3 (EN)
/B0: JVideoSlot1.23 (BO=DI(47-Ohm)), U3.9 (D7)
/B1: JVideoSlot1.46 (B1), U3.8 (D6)
/B2: JVideoSlot1.47 (B2), U3.7 (D5)
/B3: JVideoSlot1.25 (B3=DB(47-Ohm)), U3.6 (D4)
/C1: JVideoSlot1.34 (/C1_Clock), U1.4, U5.1
/C3: JVideoSlot1.53 (/C3_Clock), U1.5, U5.2
/CDAC: JP1.1 (A), JVideoSlot1.51 (CDAC_Clock)
/CSYNC: JVideoSlot1.14 (/CSYNC), U2.3 (D1)
/G0: JVideoSlot1.42 (G0), U2.9 (D7)
/G1: JVideoSlot1.43 (G1), U2.8 (D6)
/G2: JVideoSlot1.44 (G2), U2.7 (D5)
/G3: JVideoSlot1.27 (G3=DG(47-Ohm)), U2.6 (D4)
/OPTCLK: JP2.3 (B), U5.8
/PiB0: JRaspberryPiZero1.3, U3.12 (Q7)
/PiB1: JRaspberryPiZero1.5, U3.13 (Q6)
/PiB2: JRaspberryPiZero1.7, U3.14 (Q5)
/PiB3: JRaspberryPiZero1.29, U3.15 (Q4)
/PiCLK: C6.1, JRaspberryPiZero1.11, R2.1, U1.12, U2.2 (D0)
/PiCSYNC: JRaspberryPiZero1.16, U2.18 (Q1)
/PiG0: JRaspberryPiZero1.31, U2.12 (Q7)
/PiG1: JRaspberryPiZero1.26, U2.13 (Q6)
/PiG2: JRaspberryPiZero1.24, U2.14 (Q5)
/PiG3: JRaspberryPiZero1.21, U2.15 (Q4)
/PiR0: JRaspberryPiZero1.19, U2.17 (Q2)
/PiR1: JRaspberryPiZero1.23, U2.16 (Q3)
/PiR2: JRaspberryPiZero1.32, U3.17 (Q2)
/PiR3: JRaspberryPiZero1.33, U3.16 (Q3)
/R0: JVideoSlot1.38 (R0), U2.4 (D2)
/R1: JVideoSlot1.39 (R1), U2.5 (D3)
/R2: JVideoSlot1.40 (R2), U3.4 (D2)
/R3: JVideoSlot1.29 (R3=DR(47-Ohm)), U3.5 (D3)
GND: C1.2, C2.2, C3.2, C4.2, C5.2, C6.2, C7.2, JButton1.1, JButton2.1, JRaspberryPiZero1.6, JRaspberryPiZero1.9, JRaspberryPiZero1.14, JRaspberryPiZero1.20, JRaspberryPiZero1.25, JRaspberryPiZero1.30, JRaspberryPiZero1.34, JRaspberryPiZero1.39, JVideoSlot1.37 (Ground), JVideoSlot1.41 (Ground), JVideoSlot1.45 (Ground), JVideoSlot1.48 (Ground), JVideoSlot1.58 (Ground), R1.2, U1.7 (GND), U1.10, U2.1 (OE), U2.10 (GND), U3.1 (OE), U3.10 (GND), U4.2 (GND), U5.7 (GND)
unnamed: JButton1.2, JButton2.2, JRaspberryPiZero1.36
unnamed: JP1.2 (C), U1.13
unnamed: JP1.3 (B), JP2.2 (C)
unnamed: JP2.1 (A), U1.6
unnamed: JRaspberryPiZero1.12, R1.1
unnamed: R2.2, U1.8
unnamed: U1.2, U2.19 (Q0)
unnamed: U1.3, U1.9
unnamed: U1.11, U2.11 (Cp), U3.11 (Cp)
unnamed: U5.3, U5.5
unnamed: U5.6, U5.10

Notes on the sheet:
3V3
Ground
GPIO14
GPIO15
GPIO18
GPIO23
GPIO24
GPIO25
GPIO8
GPIO7
GPIO1
GPIO12
GPIO16
GPIO21
GPIO20
GPIO2
GPIO3
GPIO4
GPIO17
GPIO27
GPIO22
GPIO10
GPIO9
GPIO11
GPIO0
GPIO5
GPIO6
GPIO13
GPIO19
GPIO26

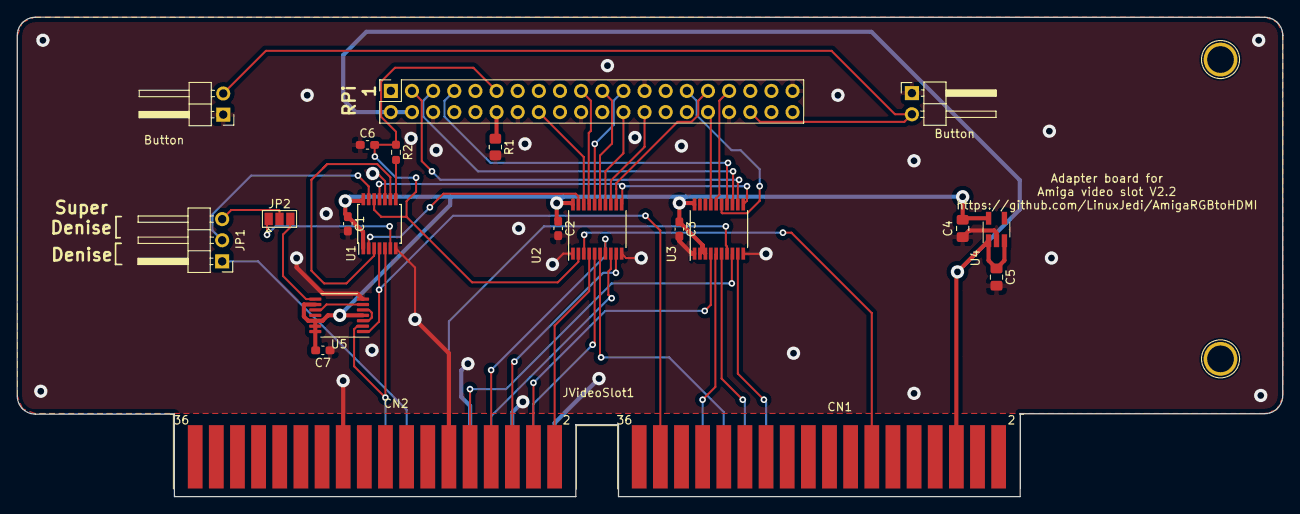
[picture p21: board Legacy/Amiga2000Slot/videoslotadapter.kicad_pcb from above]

Board: 2 copper layers, 152.0 x 57.6 mm, 20 parts (0 on the bottom side), 45 nets.

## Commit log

2021-03-28 Initial push of the Amiga 2000 slot version
    [videoslotadapter.kicad_pcb, videoslotadapter.sch]
2021-04-09 Amiga 500 CPLD variant v1
    This adds the Amiga 500 CPLD variant which does not require a Denise
    jumper and does not have the "sparkling" pixels of other variants.
    [A500-B_Cu.gbr, A500-B_Mask.gbr, A500-B_Paste.gbr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]
2021-04-09 Add schematic for Amiga 500 CPLD
2021-04-11 Add Amiga 2000 CPLD Slot design
    As yet untested
    [videoslotadapter-B_Cu.gbr, videoslotadapter-B_Mask.gbr, videoslotadapter-B_SilkS.gbr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]
2021-04-12 Amiga2000CPLDSlot v1.1
    Made the following changes after some Discord chats:
    * Added optional buttons 2 & 3
    * Added an arrow to point to the rear of the Amiga
    [videoslotadapter-B_Cu.gbr, videoslotadapter-B_Mask.gbr, videoslotadapter-B_SilkS.gbr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]
2021-04-15 Make things clearer
    * After feedback on the GPIO JTAG programming section I've made this
    clearer
    * Added silk to the A2000 CPLD slot to mark the wrong way around
    [videoslotadapter.kicad_pcb]
2021-04-17 Add Amiga 1000 CPLD design
    Needs to be a different orientation to the Amiga 500 design. Currently
    untested.
    [A1000-B_Cu.gbr, A1000-B_Mask.gbr, A1000-B_Paste.gbr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]
2021-04-26 Update A500CPLD README with beta software details
    The beta software fixes the single button mode CPLD recovery menu bug
    for us.
2021-05-05 Final tested release of Amiga 2000 CPLD edition
    [videoslotadapter-B_Cu.gbr, videoslotadapter-B_Mask.gbr, videoslotadapter-B_SilkS.gbr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]
2021-05-10 Update Amiga 1000 and READMEs
    Changes to Amiga 1000 based on feedback:
    * Added a CSYNC hook pin
    Also moved the buttons to the side as there is more space there.
    A2000 README updated as Beta20 software includes the profiles.
    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
    [A1000-B_Cu.gbr, A1000-B_Mask.gbr, A1000-B_Paste.gbr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]
2021-05-27 Fix READMEs
    Whole bunch of changes to READMEs including:
    * PCBWay links
    * New text around Beta29
    * New text around GPIO 0 pull resistor
    * Fixes to errors in the A1000 README
2021-05-28 Add bracket STL link for A2000 CPLD
2021-06-03 Fix text error for A1000 boards
    The "IF YOU CAN READ THIS" text is on the wrong side.
    [A1000-B_Cu.gbr, A1000-B_Mask.gbr, A1000-B_Paste.gbr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]
2021-06-07 Fix A500 Gerber format to be PCBWay compatible
    [A500-B_Cu.gbr, A500-B_Mask.gbr, A500-B_Paste.gbr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]
2021-06-07 Also fix A1000 Gerbers for PCBWay
    [A1000-B_Cu.gbr, A1000-B_Mask.gbr, A1000-B_Paste.gbr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]
2021-08-11 Fix A1000 BOM labelling
2021-08-16 NTSC wiring is the same as PAL for CSYNC
    Confirmed by several sources that the PAL and NTSC CSYNC comes from the
    same place, so alter the README appropriately.
2021-09-10 Update A1000 RGBtoHDMI to rev 1.3
    All SMD components are top side now. Rotated CPLD 90° for better trace
    routing.
    [A1000-B_Cu.gbr, A1000-B_Mask.gbr, A1000-B_Paste.gbr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]
2021-09-10 Add LinuxJedi logo footprints
    [A1000.kicad_pcb]
2021-09-10 Fix logo footprint issue...
    [A1000.kicad_pcb]
2021-10-06 Remove LinuxJedi logo from A1000 board
    Fixes #9
    [A1000-B_Cu.gbr, A1000-B_Mask.gbr, A1000-B_Paste.gbr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]
2022-01-09 Add Amiga 2000 CPLD v2.1
    Adds the Amiga 2000 CPLD v2.1 and moves older boards to legacy.
    [videoslotadapter-B_Cu.gbr, videoslotadapter-B_Mask.gbr, videoslotadapter-B_SilkS.gbr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]
2022-01-26 Add Amiga 500 CPLD v2
    [A500-B_Cu.gbr, A500-B_Mask.gbr, A500-B_Paste.gbr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]
2022-01-26 Add A500v2 PCBWay link
2022-11-27 Add Amiga 2000 RGBtoHDMI v2.2
    [videoslotadapter-B_Cu.gbr, videoslotadapter-B_Mask.gbr, videoslotadapter-B_Silkscreen.gbr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]

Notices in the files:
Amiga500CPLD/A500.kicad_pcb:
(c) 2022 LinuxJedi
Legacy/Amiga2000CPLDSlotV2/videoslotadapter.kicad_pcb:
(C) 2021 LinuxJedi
